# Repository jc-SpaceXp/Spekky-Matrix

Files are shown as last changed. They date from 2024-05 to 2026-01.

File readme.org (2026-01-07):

** Spekky Matrix
A FreeRTOS based project were a spectrum analyser is displayed on a LED matrix board run from a STM32 device
*** Detailed Description
A series of cascaded STP16CP05 LED IC drivers forms a 8x32 SMD (0603 Imperial)
LED matrix. This LED matrix then displays the fast fourier transform (FFT) of
an incoming audio signal picked up by a I2S digital microphone. The incoming
audio is a double buffered DMA signal. The LED matrix is driven via the
STM32's SPI interface. All while internal hardware timers and FreeRTOS are
responsible for accurate timing e.g. refresh rate of LED matrix and data
acquisition.

The Manhattan prototype uses a MAX7219 based 8x8 LED matrix breakout board
which was then cascaded to for a 8x32 LED matrix as well. In the PCB version
the STP16CP05 LED IC driver replaces the MAX7219 8x8 LED matrix.
*** Tools
The following tools are needed to build this project
- make
- [[https://developer.arm.com/downloads/-/gnu-rm][arm-none-eabi-gcc]]
- [[https://gcc.gnu.org/][gcc]] (for unit tests)
- [[https://github.com/stlink-org/stlink][st-flash]] in order to interact with the STM32
*** Progress / Milestones
- [X] Create LED matrix driver for MAX7219 devices
- [X] Drive LED matrix from STM32 using FreeRTOS
- [X] Run FFT off target
- [X] Verify FFT on target (using off target results as a guide)
- [X] Verify that LED matrix can be driven alongside FFT code (manually verified, no delays etc.)
- [X] Capture data from mic
- [X] Verify output of mic from raw logic analyser data (using SigPlotI2S)
- [X] Capture data from mic via DMA
- [X] Perform FFT on this raw logic analyser data with a sine wave test tone (off-target)
- [X] Animate FFT graphs to get a rough estimate of how the LED matrix will display it (off-target)
- [X] Perform FFT on mic data sampled by STM32 with a sine wave test tone (off-target)
- [X] Verify that LED matrix can be driven along with data capture and processing
- [X] Perform FFT on captured mic data to drive LED matrix
- [X] Adapt project to PCB
*** I2S Mic FFT Data Visualised
**** Logic Analyser Data (Sine 1kHz Test Tone)
FFT size = 64, start offset = 0, next offset = 32, FPS = 4

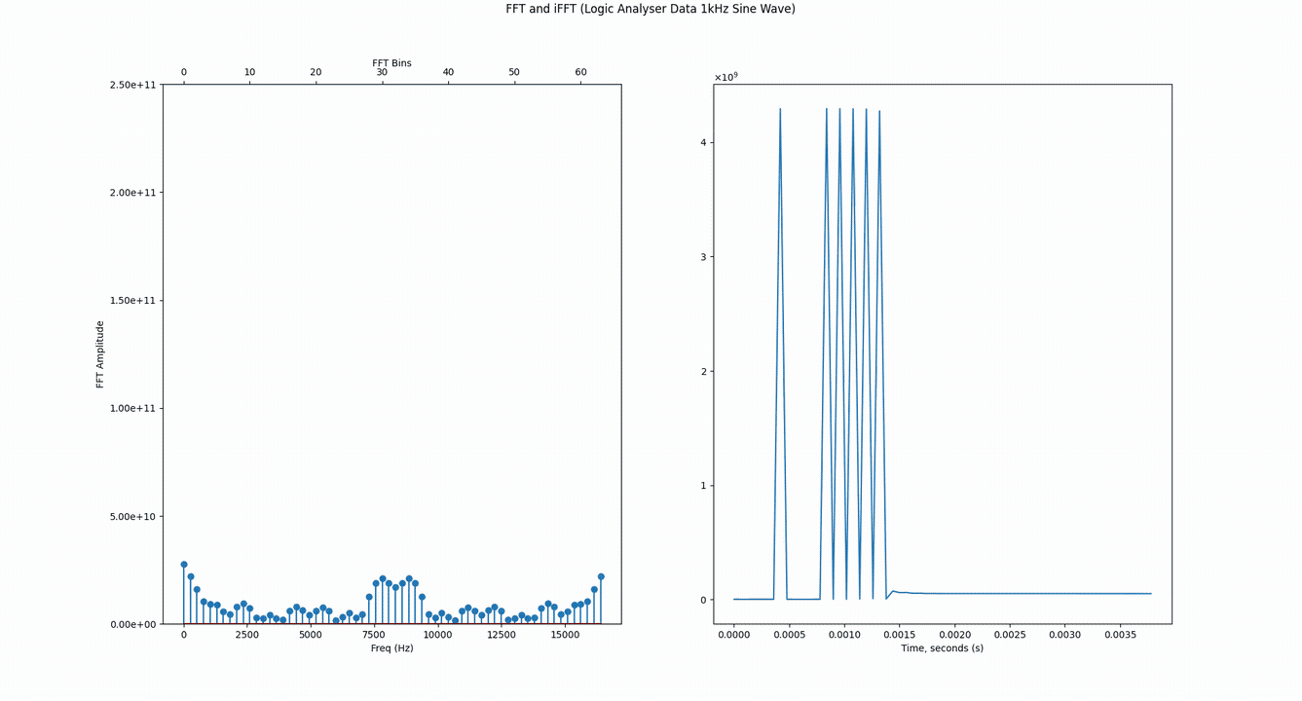
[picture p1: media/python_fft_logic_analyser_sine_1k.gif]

**** Spekky Matrix Calculations
FFT size = 64, bin resolution = (1/60E-6)/64 --> ~260Hz

Note: I measured one Ws period as 60us on PulseView hence the 1/60E-6 above
***** 8x32 LED Matrix (Sine 2kHz Test Tone)
Peak expected at the 7th/8th bin (2000 / 260 = ~7.69)

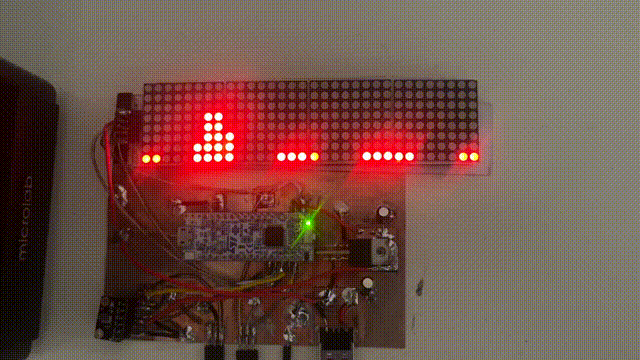
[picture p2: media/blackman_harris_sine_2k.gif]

***** 8x32 LED Matrix (Sine 4kHz Test Tone)
Peak expected at the 15th/16th bin (4000 / 260 = ~15.36)


***** 8x32 LED Matrix (Sine Sweep Test)
Since the I2S Ws period is 60us, this gives us a sampling frequency of 16.66 kHz.
 Giving us a visual representation of 0-8.88 kHz with Spekky Matrix

[[https://www.youtube.com/watch?v=dU80Fagdy28][Sine sweep source (youtube link)]]

Note: Gif is played at 2.5x speed, see mp4 for realtime playback and audio of sweep test

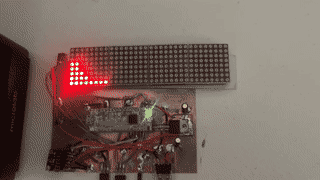
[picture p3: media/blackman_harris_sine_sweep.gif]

*** Schematic
[[file:schematic_v26.pdf]]
*** KiCad PCB
**** BOM
[[file:pcb/kicad/spekky_matrix_bom.csv]]
**** 3D Renders
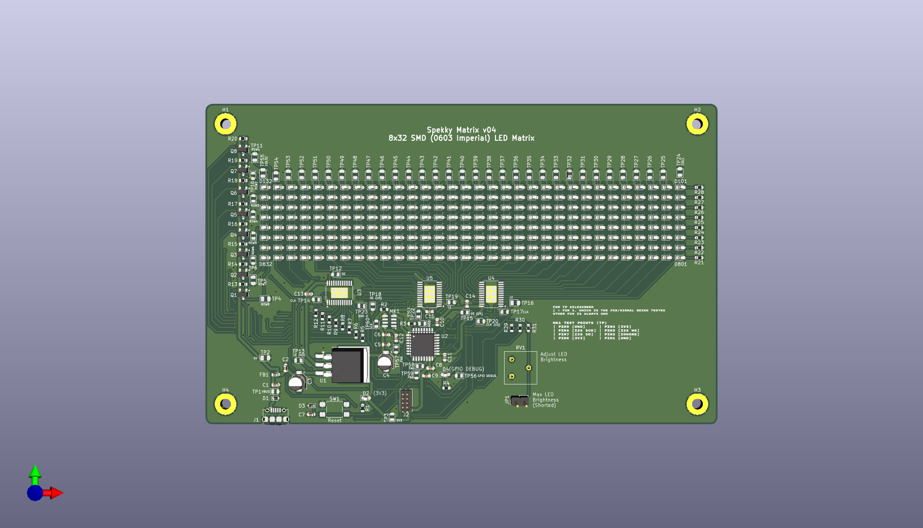
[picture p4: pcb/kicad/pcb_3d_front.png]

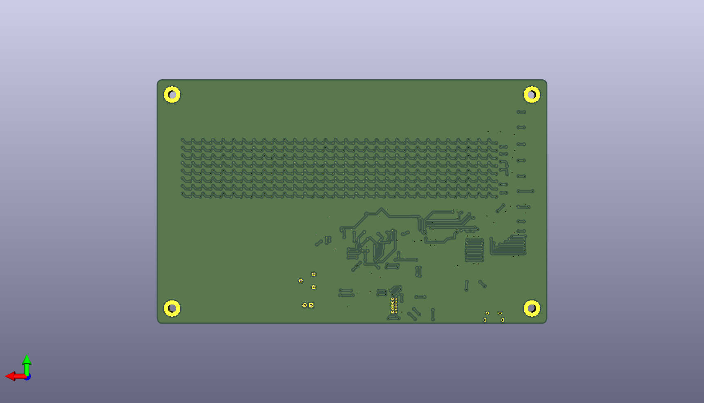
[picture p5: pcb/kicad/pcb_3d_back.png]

**** PCB v01 Test Patterns
Only displaying test patterns on PCB as v01 has the I2S footprint in the wrong orientation.

Attempted fix hasn't worked, PCB revision v04 contains fixed I2S footprint and test points.
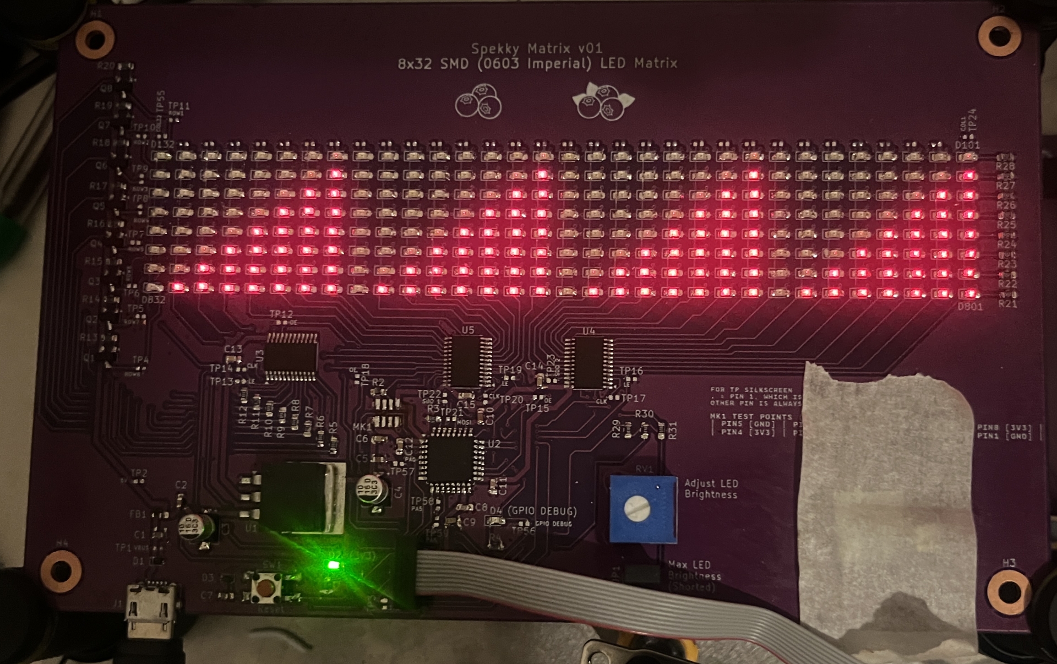
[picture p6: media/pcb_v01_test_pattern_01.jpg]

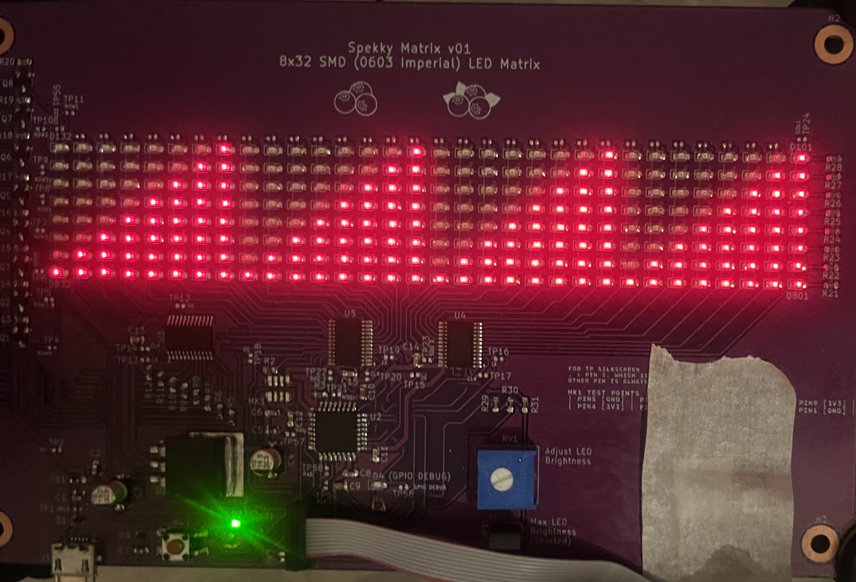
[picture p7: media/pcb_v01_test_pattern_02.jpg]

*** Execution Timeline
Rough timing of how long each task/sub-task takes to complete

Actual times are a mean of the traces from the timing branch
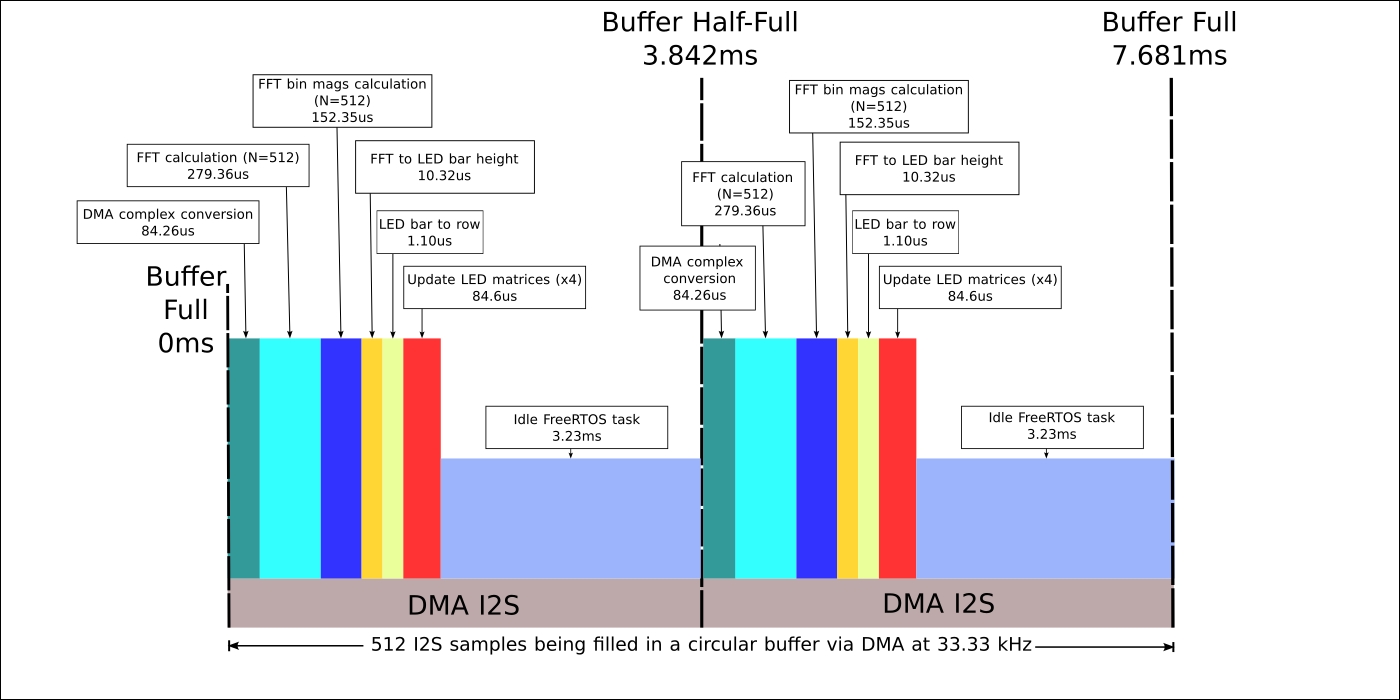
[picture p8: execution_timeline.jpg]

*** Submodules
- [[https://www.freertos.org/][FreeRTOS]]
- [[https://www.arm.com/technologies/cmsis][CMSIS V6]]
- [[https://github.com/ARM-software/CMSIS-DSP][ARM CMSIS DSP]]
- [[https://github.com/STMicroelectronics/stm32g4xx-nucleo-bsp][STM32G4xx Nucleo BSP]]
- [[https://github.com/STMicroelectronics/stm32g4xx_hal_driver][STM32G4 HAL]]
- [[https://github.com/STMicroelectronics/cmsis_device_g4][CMSIS G4]] CMSIS device library
- [[https://github.com/silentbicycle/greatest][Greatest]] C test framework
- [[https://github.com/meekrosoft/fff][fff]] C test doubles
- [[https://github.com/lucasssvaz/SigPlotI2S][SigPlotI2S]] Plot I2S PulseView/Sigrok output data

CMSIS will also produce linker warnings due to newlib e.g. "_write is not
implemented and will always fail". There is quite a bit of a size overhead
when pulling in all the CMSIS modules. An average project would be
around ~100Mb. This increases with FreeRTOS too.

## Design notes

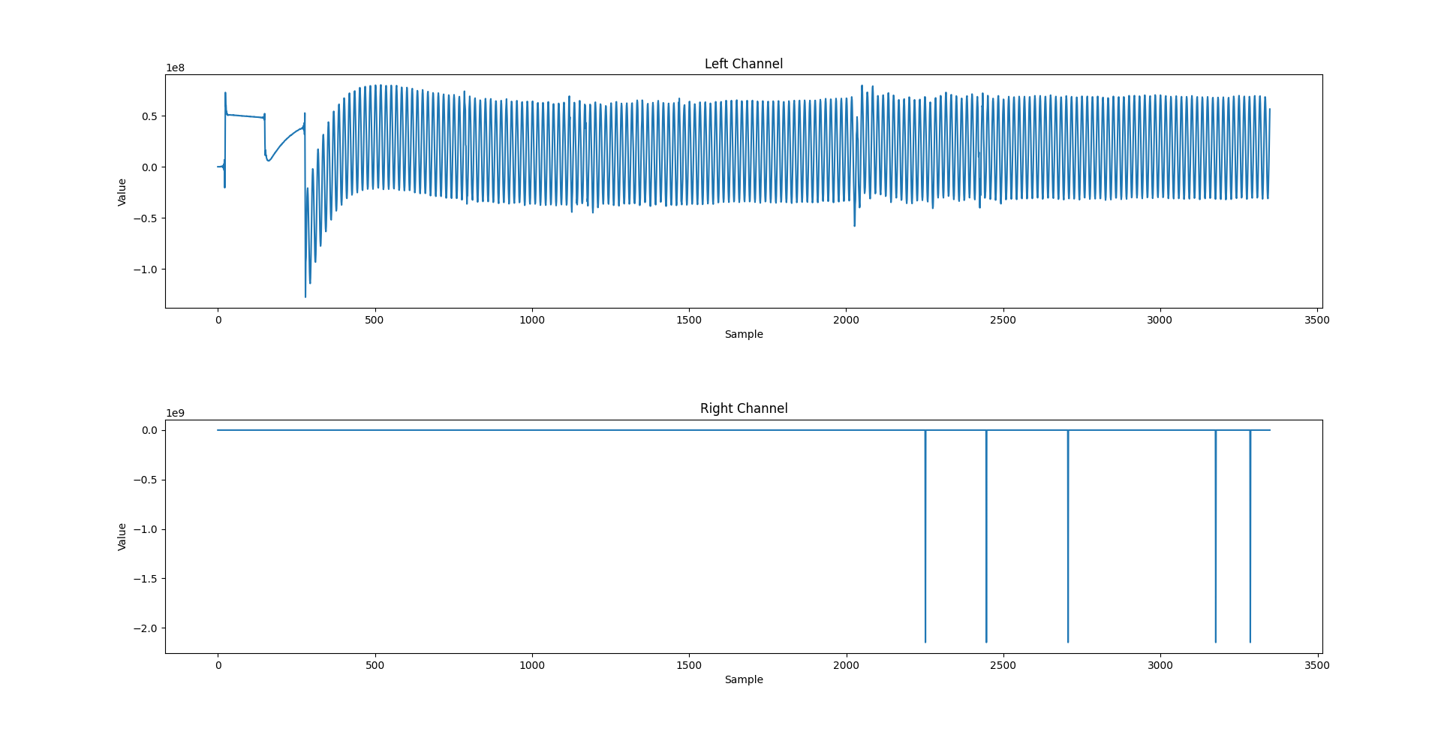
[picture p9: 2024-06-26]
traces/002_4d59f3e_fermion_mic_check_32_bit_frame_1kHz_sine_tone_on_phone_speakers_DATA_OUT.png

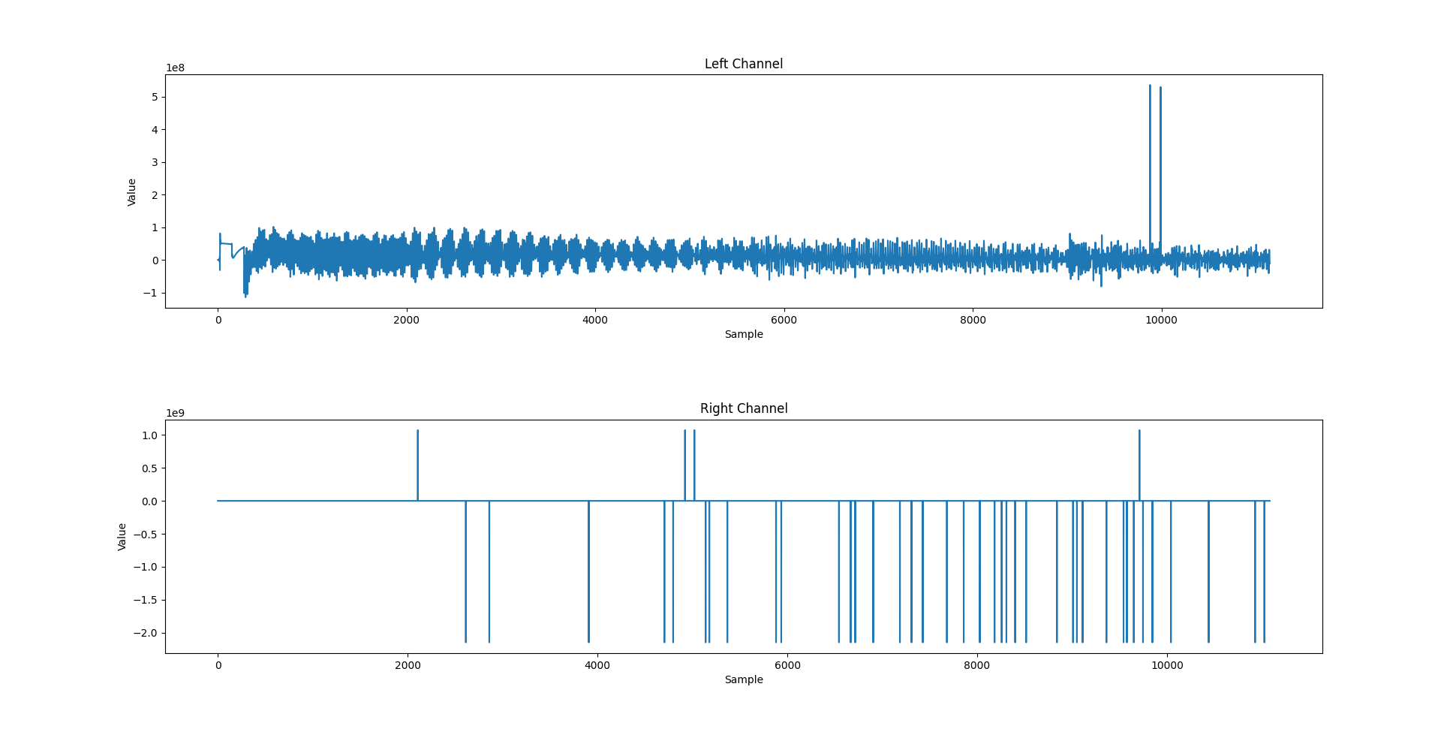
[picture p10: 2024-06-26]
traces/003_4d59f3e_fermion_mic_check_32_bit_frame_cimm_revival_on_phone_speakers_DATA_OUT.png

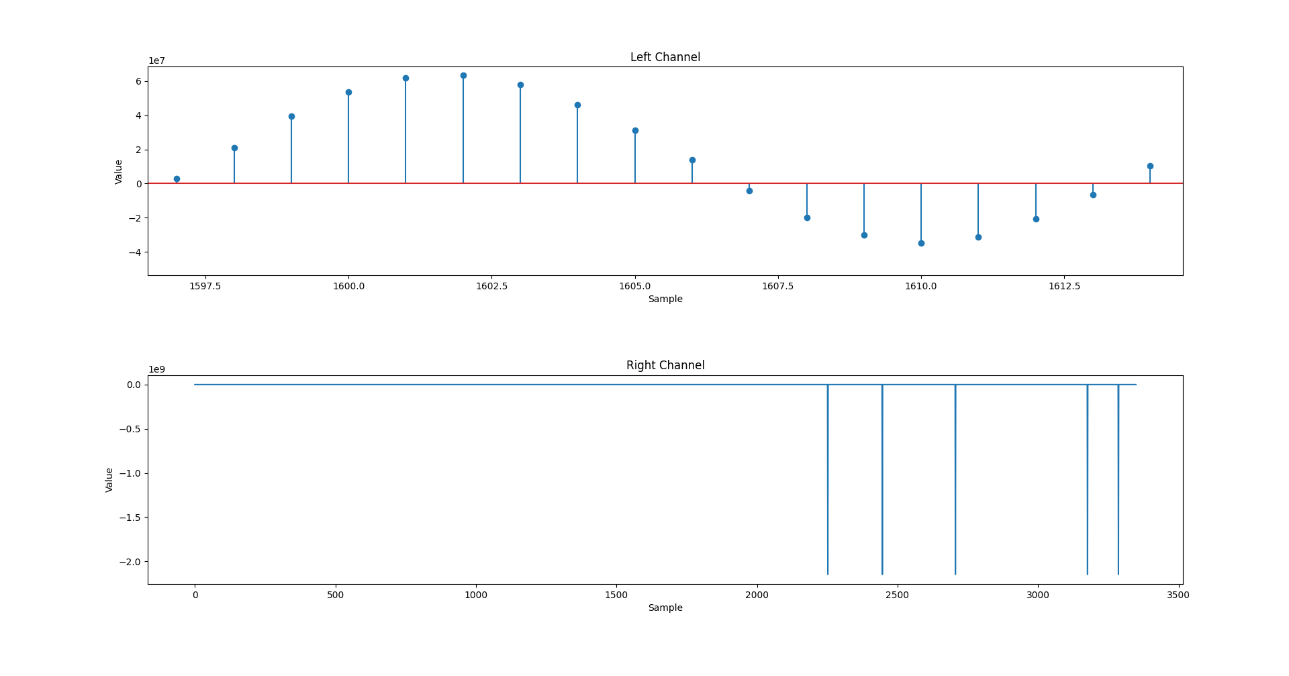
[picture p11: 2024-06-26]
traces/002_4d59f3e_fermion_mic_check_32_bit_frame_1kHz_sine_tone_on_phone_speakers_DATA_OUT_zoom_2_stem_one_period.png

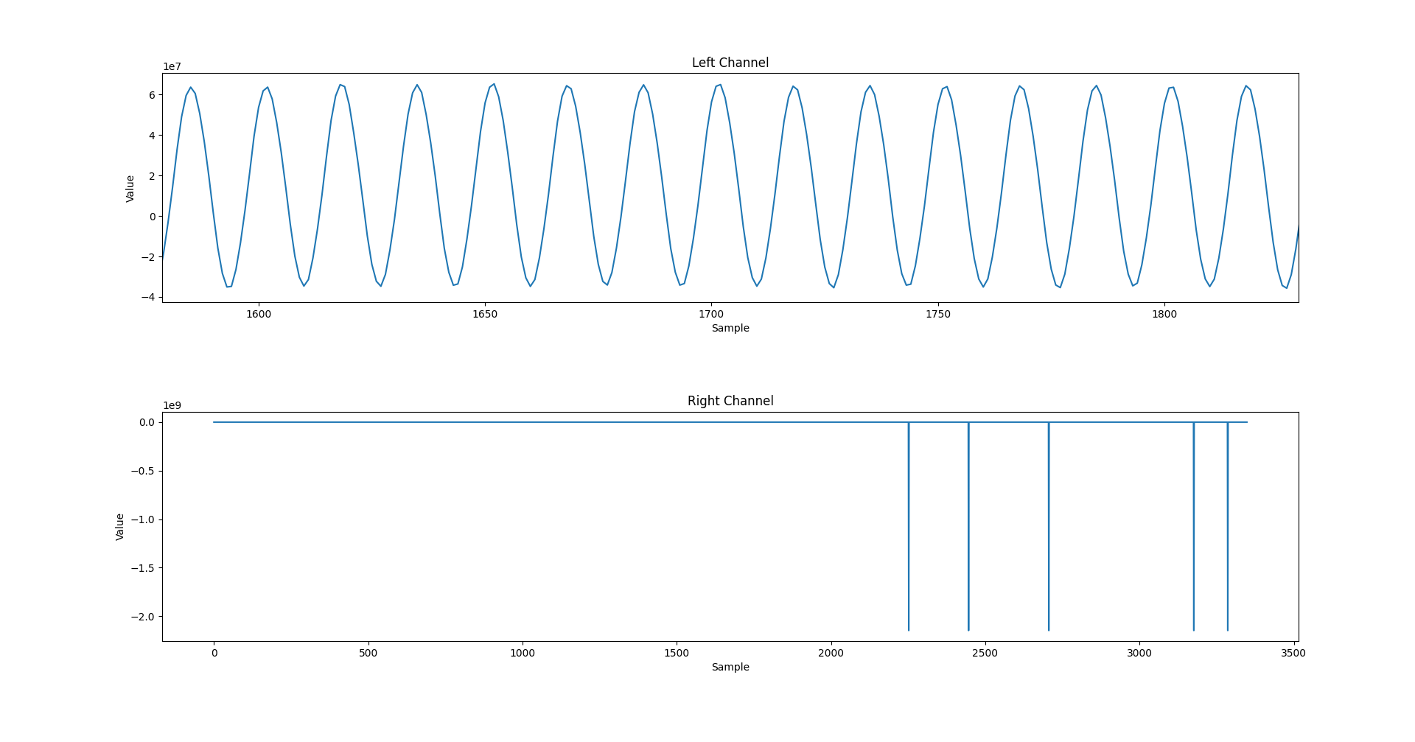
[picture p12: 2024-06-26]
traces/002_4d59f3e_fermion_mic_check_32_bit_frame_1kHz_sine_tone_on_phone_speakers_DATA_OUT_zoom_1.png

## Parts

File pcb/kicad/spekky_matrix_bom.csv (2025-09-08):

Reference | Qty | MPN | Value | Footprint | DNP
C1 | 1 | GCM188R71H103KA37J | 10n | Capacitor_SMD:C_0603_1608Metric
C2,C6-C8,C11-C15 | 9 | C0603C104J3RACTU | 100n | Capacitor_SMD:C_0603_1608Metric
C3,C4 | 2 | EDH106M016A9BAA | 10u | Capacitor_SMD:CP_Elec_4x4.5
C5 | 1 | C1608X5R1A106K080AC | 10u | Capacitor_SMD:C_0603_1608Metric
C9 | 1 | GCG188L8EE105KA07D | 1u | Capacitor_SMD:C_0603_1608Metric
C10 | 1 | GRM188Z71C475KE21D | 4u7 | Capacitor_SMD:C_0603_1608Metric
D1,D3 | 2 | PESD5V0X1UAB,115 | PESD5V0X1UAB | Diode_SMD:D_SOD-523
D2 | 1 | LTST-C190KRKT | 3V3 LED (RED) | LED_SMD:LED_0603_1608Metric_Pad1.05x0.95mm_HandSolder
D4 | 1 | LTST-C190KGKT | GPIO Debug LED (GREEN) | LED_SMD:LED_0603_1608Metric_Pad1.05x0.95mm_HandSolder
D101-D132,D201-D232,D301-D332,D401-D432,D501-D532,D601-D632,D701-D732,D801-D832 | 256 | LTST-C190KRKT | LED Matrix (RED) | LED_SMD:LED_0603_1608Metric_Pad1.05x0.95mm_HandSolder
FB1 | 1 | HI2220R301R-10 | 300R @ 100 MHz | Inductor_SMD:L_0603_1608Metric
J1 | 1 | 10118194-0001LF | USB_B_Micro | Connector_USB:USB_Micro-B_Amphenol_10118194-0001LF_Horizontal
J2 | 1 | FTSH-105-01-L-D-K | Conn_ARM_JTAG_SWD_10 | Connector_PinHeader_1.27mm:PinHeader_2x05_P1.27mm_Vertical
MK1 | 1 | MSM261S4030H0R | MSM261S4030H0R I2S Mic | spekky_matrix:LGA-8_2x4_3.0x4.0mm_P1.0mm_Hand_Solder
Q1-Q8 | 8 | DMP3125L-7 | DMP3125L-7 | Package_TO_SOT_SMD:SOT-23
R1,R4,R13-R20,R29-R31 | 13 | RT0603DRE071KL | 1K | Resistor_SMD:R_0603_1608Metric
R2 | 1 | RP73PF1J100KBTDF | 100K | Resistor_SMD:R_0603_1608Metric
R3 | 1 | RT0603FRE0710KL | 10K | Resistor_SMD:R_0603_1608Metric
R5-R12 | 8 | RT0603FRE0710RL | 10R | Resistor_SMD:R_0603_1608Metric
R21-R28 | 8 | RT0603FRE075K1L | 5K1 | Resistor_SMD:R_0603_1608Metric
RV1 | 1 | 3386F-1-222LF | 2K2 | Potentiometer_THT:Potentiometer_Bourns_3386F_Vertical
SW1 | 1 | TL3305AF260QG | SW_Push | Button_Switch_SMD:SW_SPST_TL3305A
U1 | 1 | LMS1585AIS-3.3/NOPB | LMS1585AIS-3.3 | Package_TO_SOT_SMD:TO-263-3_TabPin2
U2 | 1 | STM32G431K8T6 | STM32G431K8Tx | Package_QFP:LQFP-32_7x7mm_P0.8mm
U3-U5 | 3 | STP16CP05XTTR | STP16CP05XT | Package_SO:HTSSOP-24-1EP_4.4x7.8mm_P0.65mm_EP3.2x5mm

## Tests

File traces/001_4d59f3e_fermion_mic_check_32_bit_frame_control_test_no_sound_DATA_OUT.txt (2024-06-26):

11597-11777 I²S: : Left channel: 00000000
11777-11957 I²S: : Right channel: 00000000
11957-12137 I²S: : Left channel: 00000000
12137-12317 I²S: : Right channel: 00000000
12317-12497 I²S: : Left channel: 00000000
12497-12678 I²S: : Right channel: 00000000
12678-12858 I²S: : Left channel: 0006a300
12858-13038 I²S: : Right channel: 00000000
13038-13218 I²S: : Left channel: 00f1eb00
13218-13398 I²S: : Right channel: 00000000
13398-13578 I²S: : Left channel: 00609a00
13578-13758 I²S: : Right channel: 00000800
13758-13938 I²S: : Left channel: 005923c0
13938-14118 I²S: : Right channel: 00000000
14118-14298 I²S: : Left channel: 004cf7e0
14298-14478 I²S: : Right channel: 00000000
14478-14658 I²S: : Left channel: 0049be00
14658-14838 I²S: : Right channel: 00000000
14838-15018 I²S: : Left channel: 003e1c00
15018-15199 I²S: : Right channel: 00000000
15199-15379 I²S: : Left channel: 004659e0
15379-15559 I²S: : Right channel: 00000000
15559-15739 I²S: : Left channel: 00393de0
15739-15919 I²S: : Right channel: 00000000
15919-16099 I²S: : Left channel: 0040dfe0
16099-16279 I²S: : Right channel: 00000000
16279-16459 I²S: : Left channel: 00312a00
16459-16639 I²S: : Right channel: 00000000
16639-16819 I²S: : Left channel: 003d7a00
16819-16999 I²S: : Right channel: 00000000
16999-17179 I²S: : Left channel: 001e8400
17179-17359 I²S: : Right channel: 00000000
17359-17539 I²S: : Left channel: 006c35f0
17539-17720 I²S: : Right channel: 00000000
17720-17900 I²S: : Left channel: ff5615e0
17900-18080 I²S: : Right channel: 00000000
18080-18260 I²S: : Left channel: 051bcbe0
18260-18440 I²S: : Right channel: 00000000
18440-18620 I²S: : Left channel: 658b2bf0
18620-18800 I²S: : Right channel: 00000000
18800-18980 I²S: : Left channel: 575567f1
18980-19160 I²S: : Right channel: 00000000
19160-19340 I²S: : Left channel: 4be61800
19340-19520 I²S: : Right channel: 00000000
19520-19700 I²S: : Left channel: 533fc800
19700-19880 I²S: : Right channel: 00000000
19880-20060 I²S: : Left channel: 52f0cdf0
20060-20241 I²S: : Right channel: 00000000
20241-20421 I²S: : Left channel: 4cef8be0
20421-20601 I²S: : Right channel: 00000000
20601-20781 I²S: : Left channel: 49f40ff0
20781-20961 I²S: : Right channel: 00000000
20961-21141 I²S: : Left channel: 4266c3f0
21141-21321 I²S: : Right channel: 00000000
21321-21501 I²S: : Left channel: 40b93ff8
21501-21681 I²S: : Right channel: 00000000
21681-21861 I²S: : Left channel: 3dbad200
21861-22041 I²S: : Right channel: 00000000
22041-22221 I²S: : Left channel: 3bfc6400
22221-22401 I²S: : Right channel: 00000000
22401-22582 I²S: : Left channel: 39958400
22582-22762 I²S: : Right channel: 00000000
22762-22942 I²S: : Left channel: 38227600
22942-23122 I²S: : Right channel: 00000000
23122-23302 I²S: : Left channel: 35e7ce00
23302-23482 I²S: : Right channel: 00000000
23482-23662 I²S: : Left channel: 343d0c00
23662-23842 I²S: : Right channel: 00000000
23842-24022 I²S: : Left channel: 3250e9f0
24022-24202 I²S: : Right channel: 00000000
24202-24382 I²S: : Left channel: 30e83000
24382-24562 I²S: : Right channel: 00000000
24562-24742 I²S: : Left channel: 2fe65000
24742-24922 I²S: : Right channel: 00000000
24922-25103 I²S: : Left channel: 2e806600
25103-25283 I²S: : Right channel: 00000000
25283-25463 I²S: : Left channel: 2db89200
25463-25643 I²S: : Right channel: 00000000
25643-25823 I²S: : Left channel: 2cef0ff0
25823-26003 I²S: : Right channel: 00000000
26003-26183 I²S: : Left channel: 2c3c5600
26183-26363 I²S: : Right channel: 00000000
26363-26543 I²S: : Left channel: 2b73c1f0
26543-26723 I²S: : Right channel: 00000000
26723-26903 I²S: : Left channel: 2b0777f4
26903-27083 I²S: : Right channel: 00000000
27083-27264 I²S: : Left channel: 2ab9fdf0
27264-27444 I²S: : Right channel: 00000000
27444-27624 I²S: : Left channel: 2a5f9df0
27624-27804 I²S: : Right channel: 00000000
27804-27984 I²S: : Left channel: 298a4df8
27984-28164 I²S: : Right channel: 00000000
28164-28344 I²S: : Left channel: 2966cdf0
28344-28524 I²S: : Right channel: 00000000
28524-28704 I²S: : Left channel: 290115f4
28704-28884 I²S: : Right channel: 00000000
28884-29065 I²S: : Left channel: 286a49e0
29065-29245 I²S: : Right channel: 00000000
29245-29425 I²S: : Left channel: 289969f0
29425-29605 I²S: : Right channel: 00000000
29605-29785 I²S: : Left channel: 2814ca00
29785-29965 I²S: : Right channel: 00000000
29965-30145 I²S: : Left channel: 27d1c1f0
30145-30325 I²S: : Right channel: 00000000
30325-30505 I²S: : Left channel: 2782f400
30505-30685 I²S: : Right channel: 00000000
30685-30866 I²S: : Left channel: 27459200
30866-31046 I²S: : Right channel: 00000000
31046-31226 I²S: : Left channel: 2717abf0
31226-31406 I²S: : Right channel: 00000000
31406-31586 I²S: : Left channel: 273b6600
31586-31766 I²S: : Right channel: 00000000
31766-31946 I²S: : Left channel: 26c11ff0
31946-32126 I²S: : Right channel: 00000000
32126-32306 I²S: : Left channel: 267afff1
32306-32486 I²S: : Right channel: 00000000
32486-32666 I²S: : Left channel: 268cc600
32666-32846 I²S: : Right channel: 00000000
32846-33026 I²S: : Left channel: 25e33c00
33026-33206 I²S: : Right channel: 00000000
33206-33386 I²S: : Left channel: 26351800
33386-33567 I²S: : Right channel: 00000000
33567-33747 I²S: : Left channel: 25a55de0
33747-33927 I²S: : Right channel: 00000000
33927-34107 I²S: : Left channel: 26890600
34107-34287 I²S: : Right channel: 00000000
34287-34467 I²S: : Left channel: 25aba600
34467-34647 I²S: : Right channel: 00000000
34647-34827 I²S: : Left channel: 260ee000
34827-35007 I²S: : Right channel: 00000000
35007-35187 I²S: : Left channel: 24dea7f4
35187-35367 I²S: : Right channel: 00000000
35367-35547 I²S: : Left channel: 252b9bf0
35547-35728 I²S: : Right channel: 00000000
35728-35908 I²S: : Left channel: 253e1ff0
35908-36088 I²S: : Right channel: 00000000
36088-36268 I²S: : Left channel: 24f047f0
36268-36448 I²S: : Right channel: 00000000
36448-36628 I²S: : Left channel: 25274e00
36628-36808 I²S: : Right channel: 00000000
36808-36988 I²S: : Left channel: 2437b600
36988-37168 I²S: : Right channel: 00000000
37168-37349 I²S: : Left channel: 252b75f0
37349-37529 I²S: : Right channel: 00000000
37529-37709 I²S: : Left channel: 2490e5f2
37709-37889 I²S: : Right channel: 00000000
37889-38069 I²S: : Left channel: 2484f9f0
38069-38249 I²S: : Right channel: 00000000
38249-38429 I²S: : Left channel: 24a403f0
38429-38609 I²S: : Right channel: 00000000
38609-38790 I²S: : Left channel: 23c8f1e0
38790-38970 I²S: : Right channel: 00000000
38970-39150 I²S: : Left channel: 248a8800
39150-39330 I²S: : Right channel: 00000000
39330-39510 I²S: : Left channel: 24653ff8
39510-39690 I²S: : Right channel: 00000000
39690-39870 I²S: : Left channel: 243a7ff0
39870-40050 I²S: : Right channel: 00000000
40050-40230 I²S: : Left channel: 2407dc00
40230-40410 I²S: : Right channel: 00000000
40410-40590 I²S: : Left channel: 23da9a00
40590-40771 I²S: : Right channel: 00000000
40771-40951 I²S: : Left channel: 24993c00
40951-41131 I²S: : Right channel: 00000000
41131-41311 I²S: : Left channel: 2379bc00
41311-41491 I²S: : Right channel: 00000000
41491-41671 I²S: : Left channel: 23e52600
41671-41851 I²S: : Right channel: 00000000
41851-42031 I²S: : Left channel: 23a07e00
42031-42211 I²S: : Right channel: 00000000
42211-42391 I²S: : Left channel: 231f2400
42391-42571 I²S: : Right channel: 00000000
42571-42751 I²S: : Left channel: 23a36800
42751-42931 I²S: : Right channel: 00000000
42931-43111 I²S: : Left channel: 231a0600
43111-43292 I²S: : Right channel: 00000000
43292-43472 I²S: : Left channel: 2355b600
43472-43652 I²S: : Right channel: 00000000
43652-43832 I²S: : Left channel: 23108400
43832-44012 I²S: : Right channel: 00000000
44012-44192 I²S: : Left channel: 2260eff8
44192-44372 I²S: : Right channel: 00000000
44372-44552 I²S: : Left channel: 2318a800
44552-44732 I²S: : Right channel: 00000000
44732-44912 I²S: : Left channel: 22d41600
44912-45092 I²S: : Right channel: 00000000
45092-45272 I²S: : Left channel: 22200600
45272-45452 I²S: : Right channel: 00000000
45452-45633 I²S: : Left channel: 22c137e0
45633-45813 I²S: : Right channel: 00000000
45813-45993 I²S: : Left channel: 228fc200
45993-46173 I²S: : Right channel: 00000000
46173-46353 I²S: : Left channel: 2227a5f0
46353-46533 I²S: : Right channel: 00000000
46533-46713 I²S: : Left channel: 22a72200
46713-46893 I²S: : Right channel: 00000000
46893-47073 I²S: : Left channel: 220f4400
47073-47253 I²S: : Right channel: 00000000
47253-47433 I²S: : Left channel: 2252fff0
47433-47613 I²S: : Right channel: 00000000
47613-47793 I²S: : Left channel: 22ac8800
47793-47973 I²S: : Right channel: 00000000
47973-48153 I²S: : Left channel: 21f74000
48153-48333 I²S: : Right channel: 00000000
48333-48513 I²S: : Left channel: 22304000
48513-48693 I²S: : Right channel: 00000000
48693-48874 I²S: : Left channel: 22a8bfe0
48874-49054 I²S: : Right channel: 00000000
49054-49234 I²S: : Left channel: 21f61200
49234-49414 I²S: : Right channel: 00000000
49414-49594 I²S: : Left channel: 2227c000
49594-49774 I²S: : Right channel: 00000000
49774-49954 I²S: : Left channel: 21dd8df0
49954-50134 I²S: : Right channel: 00000000
50134-50314 I²S: : Left channel: 212ad9f0
50314-50494 I²S: : Right channel: 00000000
50494-50674 I²S: : Left channel: 21ef0800
50674-50854 I²S: : Right channel: 00000000
50854-51034 I²S: : Left channel: 21d6cbf0
51034-51214 I²S: : Right channel: 00000000
51214-51394 I²S: : Left channel: 213c99f0
51394-51575 I²S: : Right channel: 00000000
51575-51755 I²S: : Left channel: 21c4f7e0
51755-51935 I²S: : Right channel: 00000000
51935-52115 I²S: : Left channel: 216b53f0
52115-52295 I²S: : Right channel: 00000000
52295-52475 I²S: : Left channel: 2176c200
52475-52655 I²S: : Right channel: 00000000
52655-52835 I²S: : Left channel: 218e13f0
52835-53015 I²S: : Right channel: 00000000
53015-53195 I²S: : Left channel: 215ff5f0
53195-53375 I²S: : Right channel: 00000000
53375-53555 I²S: : Left channel: 2179b3f0
53555-53735 I²S: : Right channel: 00000000
53735-53915 I²S: : Left channel: 210713f0
53915-54095 I²S: : Right channel: 00000000
54095-54275 I²S: : Left channel: 20ac9bf0
54275-54455 I²S: : Right channel: 00000000
54455-54635 I²S: : Left channel: 215cb5f0
54635-54815 I²S: : Right channel: 00000000
54815-54996 I²S: : Left channel: 20f605f0
54996-55176 I²S: : Right channel: 00000000
55176-55356 I²S: : Left channel: 20b47c00
55356-55536 I²S: : Right channel: 00000000
55536-55716 I²S: : Left channel: 21225800
55716-55896 I²S: : Right channel: 00000000
55896-56076 I²S: : Left channel: 2093ac00
56076-56256 I²S: : Right channel: 00000000
56256-56436 I²S: : Left channel: 20e39000
56436-56616 I²S: : Right channel: 00000000
56616-56796 I²S: : Left channel: 20f6cff0
56796-56976 I²S: : Right channel: 00000000
56976-57156 I²S: : Left channel: 204645f0
57156-57336 I²S: : Right channel: 00000000
57336-57516 I²S: : Left channel: 20f3c5e0
57516-57696 I²S: : Right channel: 00000000
57696-57877 I²S: : Left channel: 2104e5e0
57877-58057 I²S: : Right channel: 00000000
58057-58237 I²S: : Left channel: 206fa7f2
58237-58417 I²S: : Right channel: 00000000
58417-58597 I²S: : Left channel: 20d0d5f0
58597-58777 I²S: : Right channel: 00000000
58777-58957 I²S: : Left channel: 209257f0
58957-59137 I²S: : Right channel: 00000000
59137-59317 I²S: : Left channel: 204337f8
59317-59497 I²S: : Right channel: 00000000
59497-59677 I²S: : Left channel: 20888400
59677-59857 I²S: : Right channel: 00000000
59857-60037 I²S: : Left channel: 20727a00
60037-60217 I²S: : Right channel: 00000000
60217-60397 I²S: : Left channel: 200187f0
60397-60577 I²S: : Right channel: 00000000
60577-60758 I²S: : Left channel: 20673ff0
60758-60938 I²S: : Right channel: 00000000
60938-61118 I²S: : Left channel: 206aca00
61118-61298 I²S: : Right channel: 00000000
61298-61478 I²S: : Left channel: 1fc1f7f0
61478-61658 I²S: : Right channel: 00000000
61658-61838 I²S: : Left channel: 2050bdf1
61838-62018 I²S: : Right channel: 00000000
62018-62198 I²S: : Left channel: 2041a000
62198-62378 I²S: : Right channel: 00000000
62378-62558 I²S: : Left channel: 1fab9fe0
62558-62738 I²S: : Right channel: 00000000
62738-62919 I²S: : Left channel: 1fffadf0
62919-63099 I²S: : Right channel: 00000000
63099-63279 I²S: : Left channel: 1ff23800
63279-63459 I²S: : Right channel: 00000000
63459-63639 I²S: : Left channel: 1f713df0
63639-63819 I²S: : Right channel: 00000000
63819-63999 I²S: : Left channel: 201225f0
63999-64179 I²S: : Right channel: 00000000
64179-64359 I²S: : Left channel: 1ff0d800
64359-64539 I²S: : Right channel: 00000000
64539-64719 I²S: : Left channel: 1fbdcdf0
64719-64899 I²S: : Right channel: 00000000
64899-65080 I²S: : Left channel: 200527e0
65080-65260 I²S: : Right channel: 00000000
65260-65440 I²S: : Left channel: 1ff08800
65440-65620 I²S: : Right channel: 00000000
65620-65800 I²S: : Left channel: 20007800
65800-65980 I²S: : Right channel: 00000000
65980-66160 I²S: : Left channel: 1fd50bf0
66160-66340 I²S: : Right channel: 00000000
66340-66520 I²S: : Left channel: 1f7b5ff8
66520-66700 I²S: : Right channel: 00000000
66700-66880 I²S: : Left channel: 1ff3fa00
66880-67060 I²S: : Right channel: 00000000
67060-67240 I²S: : Left channel: 1fb6ac00
67240-67420 I²S: : Right channel: 00000000
67420-67600 I²S: : Left channel: 1f889c00
67600-67780 I²S: : Right channel: 00000000
67780-67960 I²S: : Left channel: 1fd255f0
67960-68140 I²S: : Right channel: 00000000
68140-68320 I²S: : Left channel: 1f733bf0
68320-68500 I²S: : Right channel: 00000000
68500-68680 I²S: : Left channel: 1f792800
68680-68861 I²S: : Right channel: 00000000
68861-69041 I²S: : Left channel: 1fe78a00
69041-69221 I²S: : Right channel: 00000000
69221-69401 I²S: : Left channel: 1f8e1000
69401-69581 I²S: : Right channel: 00000000
69581-69761 I²S: : Left channel: 1f6c09f8
69761-69941 I²S: : Right channel: 00000000
69941-70121 I²S: : Left channel: 1fa7dc00
70121-70301 I²S: : Right channel: 00000000
70301-70481 I²S: : Left channel: 1ef283f0
70481-70661 I²S: : Right channel: 00000000
70661-70841 I²S: : Left channel: 1f8555f0
70841-71021 I²S: : Right channel: 00000000
71021-71201 I²S: : Left channel: 1fa01c00
71201-71381 I²S: : Right channel: 00000000
71381-71561 I²S: : Left channel: 1f105a00
71561-71742 I²S: : Right channel: 00000000
71742-71922 I²S: : Left channel: 1f2b1c00
71922-72102 I²S: : Right channel: 00000000
72102-72282 I²S: : Left channel: 1f1f39f0
72282-72462 I²S: : Right channel: 00000000
72462-72642 I²S: : Left channel: 1e94ec00
72642-72822 I²S: : Right channel: 00000000
72822-73002 I²S: : Left channel: 1ef0e800
73002-73182 I²S: : Right channel: 00000000
73182-73362 I²S: : Left channel: 1ef651d0
73362-73542 I²S: : Right channel: 00000000
73542-73722 I²S: : Left channel: 1ebf3a00
73722-73902 I²S: : Right channel: 00000000
73902-74083 I²S: : Left channel: 1f08ddf0
74083-74263 I²S: : Right channel: 00000000
74263-74443 I²S: : Left channel: 1ea53e00
74443-74623 I²S: : Right channel: 00000000
74623-74803 I²S: : Left channel: 1e83f9f0
74803-74983 I²S: : Right channel: 00000000
74983-75163 I²S: : Left channel: 1f666400
75163-75343 I²S: : Right channel: 00000000
75343-75523 I²S: : Left channel: 1ef651f0
75523-75703 I²S: : Right channel: 00000000
75703-75883 I²S: : Left channel: 1eafd000
75883-76063 I²S: : Right channel: 00000000
76063-76243 I²S: : Left channel: 1ecfc000
76243-76423 I²S: : Right channel: 00000000
76423-76603 I²S: : Left channel: 1f118200
76603-76783 I²S: : Right channel: 00000000
76783-76963 I²S: : Left channel: 1e588800
76963-77143 I²S: : Right channel: 00000000
77143-77324 I²S: : Left channel: 1ecdabe0
77324-77504 I²S: : Right channel: 00000000
77504-77684 I²S: : Left channel: 1efc8be0
77684-77864 I²S: : Right channel: 00000000
77864-78044 I²S: : Left channel: 1e937200
78044-78224 I²S: : Right channel: 00000000
78224-78404 I²S: : Left channel: 1e431200
78404-78584 I²S: : Right channel: 00000000
78584-78764 I²S: : Left channel: 1e57f9f8
78764-78944 I²S: : Right channel: 00000000
78944-79124 I²S: : Left channel: 1ea55a00
79124-79304 I²S: : Right channel: 00000000
79304-79484 I²S: : Left channel: 1e5955f1
79484-79664 I²S: : Right channel: 00000000
79664-79844 I²S: : Left channel: 1df237f0
79844-80024 I²S: : Right channel: 00000000
80024-80204 I²S: : Left channel: 1e51f7f0
80204-80384 I²S: : Right channel: 00000000
80384-80564 I²S: : Left channel: 1dd01a00
80564-80744 I²S: : Right channel: 00000000
80744-80924 I²S: : Left channel: 1df805f0
80924-81105 I²S: : Right channel: 00000000
81105-81285 I²S: : Left channel: 1e3b1de0
81285-81465 I²S: : Right channel: 00000000
81465-81645 I²S: : Left channel: 1dad3000
81645-81825 I²S: : Right channel: 00000000
81825-82005 I²S: : Left channel: 1df18a00
82005-82185 I²S: : Right channel: 00000000
82185-82365 I²S: : Left channel: 1e177000
82365-82545 I²S: : Right channel: 00000000
82545-82725 I²S: : Left channel: 1d9511f0
82725-82905 I²S: : Right channel: 00000000
82905-83085 I²S: : Left channel: 1e1b53f0
83085-83265 I²S: : Right channel: 00000000
83265-83446 I²S: : Left channel: 1dfc5e00
83446-83626 I²S: : Right channel: 00000000
83626-83806 I²S: : Left channel: 1df7fbf0
83806-83986 I²S: : Right channel: 00000000
83986-84166 I²S: : Left channel: 1e0f9800
84166-84346 I²S: : Right channel: 00000000
84346-84526 I²S: : Left channel: 1e6211f0
84526-84706 I²S: : Right channel: 00000000
84706-84886 I²S: : Left channel: 1e022600
84886-85067 I²S: : Right channel: 00000000
85067-85247 I²S: : Left channel: 1e4cc800
85247-85427 I²S: : Right channel: 00000000
85427-85607 I²S: : Left channel: 1df86600
85607-85787 I²S: : Right channel: 00000000
85787-85967 I²S: : Left channel: 1d83c5f0
85967-86147 I²S: : Right channel: 00000000
86147-86327 I²S: : Left channel: 1e213e00
86327-86507 I²S: : Right channel: 00000000
86507-86687 I²S: : Left channel: 1ddeddf0
86687-86868 I²S: : Right channel: 00000000
86868-87048 I²S: : Left channel: 1d210800
87048-87228 I²S: : Right channel: 00000000
87228-87408 I²S: : Left channel: 1d710e00
87408-87588 I²S: : Right channel: 00000000
87588-87768 I²S: : Left channel: 1d9fb9f0
87768-87948 I²S: : Right channel: 00000000
87948-88128 I²S: : Left channel: 1d014c00
88128-88309 I²S: : Right channel: 00000000
88309-88489 I²S: : Left channel: 1d77cbe0
88489-88669 I²S: : Right channel: 00000000
88669-88849 I²S: : Left channel: 1d525000
88849-89029 I²S: : Right channel: 00000000
89029-89209 I²S: : Left channel: 1d1aae00
89209-89389 I²S: : Right channel: 00000000
89389-89569 I²S: : Left channel: 1d384e00
89569-89750 I²S: : Right channel: 00000000
89750-89930 I²S: : Left channel: 1d301de0
89930-90110 I²S: : Right channel: 00000000
90110-90290 I²S: : Left channel: 1d480e00
90290-90470 I²S: : Right channel: 00000000
90470-90650 I²S: : Left channel: 1d4b49f0
90650-90830 I²S: : Right channel: 00000000
90830-91010 I²S: : Left channel: 1cdace00
91010-91190 I²S: : Right channel: 00000000
91190-91371 I²S: : Left channel: 1cea2df0
91371-91551 I²S: : Right channel: 00000000
91551-91731 I²S: : Left channel: 1cd80df0
91731-91911 I²S: : Right channel: 00000000
91911-92091 I²S: : Left channel: 1d40d000
92091-92271 I²S: : Right channel: 00000000
92271-92451 I²S: : Left channel: 1d4fe000
92451-92631 I²S: : Right channel: 00000000
92631-92812 I²S: : Left channel: 1cd85fe0
92812-92992 I²S: : Right channel: 00000000
92992-93172 I²S: : Left channel: 1cf09ff0
93172-93352 I²S: : Right channel: 00000000
93352-93532 I²S: : Left channel: 1d37b3f0
93532-93712 I²S: : Right channel: 00000000
93712-93892 I²S: : Left channel: 1ce579d0
93892-94072 I²S: : Right channel: 00000000
94072-94252 I²S: : Left channel: 1d220a00
94252-94433 I²S: : Right channel: 00000000
94433-94613 I²S: : Left channel: 1d180400
94613-94793 I²S: : Right channel: 00000000
94793-94973 I²S: : Left channel: 1cd991f0
94973-95153 I²S: : Right channel: 00000000
95153-95333 I²S: : Left channel: 1ced15f0
95333-95513 I²S: : Right channel: 00000000
95513-95694 I²S: : Left channel: 1d099e00
95694-95874 I²S: : Right channel: 00000000
95874-96054 I²S: : Left channel: 1cc8dff0
96054-96234 I²S: : Right channel: 00000000
96234-96414 I²S: : Left channel: 1cb7f5f1
96414-96594 I²S: : Right channel: 00000000
96594-96774 I²S: : Left channel: 1cd89ff0
96774-96954 I²S: : Right channel: 00000000
96954-97135 I²S: : Left channel: 1c46bdf0
97135-97315 I²S: : Right channel: 00000000
97315-97495 I²S: : Left channel: 1c9a9200
97495-97675 I²S: : Right channel: 00000000
97675-97855 I²S: : Left channel: 1c39d3f0
97855-98035 I²S: : Right channel: 00000000
98035-98215 I²S: : Left channel: 1c557e00
98215-98396 I²S: : Right channel: 00000000
98396-98576 I²S: : Left channel: 1c2767f0
98576-98756 I²S: : Right channel: 00000000
98756-98936 I²S: : Left channel: 1bf541f1
98936-99116 I²S: : Right channel: 00000000
99116-99296 I²S: : Left channel: 1bf885f0
99296-99477 I²S: : Right channel: 00000000
99477-99657 I²S: : Left channel: 1c75c200
99657-99837 I²S: : Right channel: 00000000
99837-100017 I²S: : Left channel: 1c1f19f1
100017-100197 I²S: : Right channel: 00000000
100197-100377 I²S: : Left channel: 1c60abf0
100377-100558 I²S: : Right channel: 00000000
100558-100738 I²S: : Left channel: 1c2491f0
100738-100918 I²S: : Right channel: 00000000
100918-101098 I²S: : Left channel: 1c4491f0
101098-101278 I²S: : Right channel: 00000000
101278-101458 I²S: : Left channel: 1c669600
101458-101639 I²S: : Right channel: 00000000
101639-101819 I²S: : Left channel: 1c20c400
101819-101999 I²S: : Right channel: 00000000
101999-102179 I²S: : Left channel: 1c87e200
102179-102359 I²S: : Right channel: 00000000
102359-102539 I²S: : Left channel: 1c611df0
102539-102719 I²S: : Right channel: 00000000
102719-102900 I²S: : Left channel: 1bcaf5f0
102900-103080 I²S: : Right channel: 00000000
103080-103260 I²S: : Left channel: 1c4d2e00
103260-103440 I²S: : Right channel: 00000000
103440-103620 I²S: : Left channel: 1c26be00
103620-103800 I²S: : Right channel: 00000000
103800-103980 I²S: : Left channel: 1bd2b1f0
103980-104160 I²S: : Right channel: 00000000
104160-104340 I²S: : Left channel: 1c3a3bf0
104340-104520 I²S: : Right channel: 00000000
104520-104701 I²S: : Left channel: 1c458000
104701-104881 I²S: : Right channel: 00000000
104881-105061 I²S: : Left channel: 1befcdf0
105061-105241 I²S: : Right channel: 00000000
105241-105421 I²S: : Left channel: 1bdeddf0
105421-105601 I²S: : Right channel: 00000000
105601-105781 I²S: : Left channel: 1beecbf0
105781-105961 I²S: : Right channel: 00000000
105961-106141 I²S: : Left channel: 1bea79e0
106141-106321 I²S: : Right channel: 00000000
106321-106501 I²S: : Left channel: 1bd87e00
106501-106681 I²S: : Right channel: 00000000
106681-106862 I²S: : Left channel: 1bb3a5f0
106862-107042 I²S: : Right channel: 00000000
107042-107222 I²S: : Left channel: 1bd9be00
107222-107402 I²S: : Right channel: 00000000
107402-107582 I²S: : Left channel: 1bca4400
107582-107762 I²S: : Right channel: 00000000
107762-107942 I²S: : Left channel: 1b759000
107942-108122 I²S: : Right channel: 00000000
108122-108302 I²S: : Left channel: 1bc1b3f0
108302-108482 I²S: : Right channel: 00000000
108482-108663 I²S: : Left channel: 1b5c0000
108663-108843 I²S: : Right channel: 00000000
108843-109023 I²S: : Left channel: 1b562bf0
109023-109203 I²S: : Right channel: 00000000
109203-109383 I²S: : Left channel: 1b943a00
109383-109563 I²S: : Right channel: 00000000
109563-109743 I²S: : Left channel: 1b492200
109743-109923 I²S: : Right channel: 00000000
109923-110103 I²S: : Left channel: 1b8a6600
110103-110283 I²S: : Right channel: 00000000
110283-110463 I²S: : Left channel: 1b8267f0
110463-110643 I²S: : Right channel: 00000000
110643-110823 I²S: : Left channel: 1b934df0
110823-111003 I²S: : Right channel: 00000000
111003-111184 I²S: : Left channel: 1ba54400
111184-111364 I²S: : Right channel: 00000000
111364-111544 I²S: : Left channel: 1b794e00
111544-111724 I²S: : Right channel: 00000000
111724-111904 I²S: : Left channel: 1b27de00
111904-112084 I²S: : Right channel: 00000000
112084-112264 I²S: : Left channel: 1ba75200
112264-112444 I²S: : Right channel: 00000000
112444-112624 I²S: : Left channel: 1b8049f0
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

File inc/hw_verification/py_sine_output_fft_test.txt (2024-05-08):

(8.284213399999999+0j)
(8.62636695114758-4.424957927965547j)
(9.837655582397456-10.04498064851128j)
(12.794667938009676-19.44358075520538j)
(21.79799241098727-43.69024457265637j)
(185.8862500637988-459.33900737222393j)
(-23.454165006306724+68.40280056615032j)
(-10.268408946519799+34.27125015501009j)
(-6.328246943716139+23.617591005544597j)
(-4.47101654120538+18.3241927030198j)
(-3.4080363581534416+15.116500123472981j)
(-2.72896578329462+12.943286370280983j)
(-2.263054899871338+11.361925306020034j)
(-1.9268740575397167+10.152844572073938j)
(-1.6749973412965635+9.194310393498727j)
(-1.480675546412971+8.413152678134779j)
(-1.3271911984704772+7.762601957291322j)
(-1.203596782292827+7.2112821205525774j)
(-1.102445324614854+6.737304691649097j)
(-1.0185108096820814+6.324900803844347j)
(-0.9480277848889226+5.962399745092216j)
(-0.8882215032173445+5.640963865662353j)
(-0.8370071447925542+5.353767901379721j)
(-0.792791445801196+5.095449964509767j)
(-0.7543384331549321+4.861734326033611j)
(-0.7206764899426952+4.649166080864622j)
(-0.6910321576714782+4.454920791830286j)
(-0.6647845770218662+4.276664588194248j)
(-0.6414284226252369+4.11245136637583j)
(-0.6205502248551666+3.9606439572103445j)
(-0.6018084180172082+3.819854534934694j)
(-0.5849187785819921+3.6888982725001123j)
(-0.5696431718500778+3.5667570721919253j)
(-0.5557808071161664+3.4525508763208888j)
(-0.5431613800246243+3.345514759331028j)
(-0.531639646845725+3.2449804798143167j)
(-0.5210911685190256+3.150361374577602j)
(-0.5114085507699468+3.0611406243841364j)
(-0.5024991425033886+2.9768602353079214j)
(-0.4942822907519545+2.897113502264887j)
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

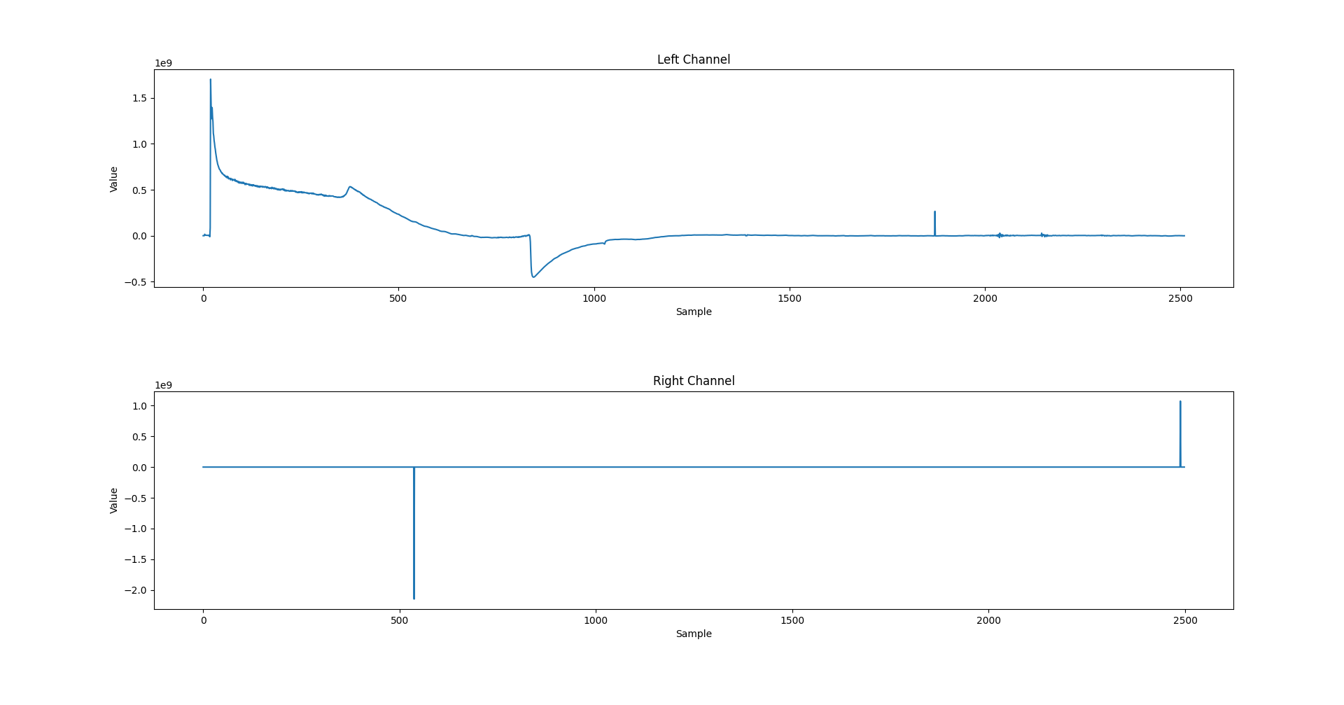
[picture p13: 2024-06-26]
traces/001_4d59f3e_fermion_mic_check_32_bit_frame_control_test_no_sound_DATA_OUT.png

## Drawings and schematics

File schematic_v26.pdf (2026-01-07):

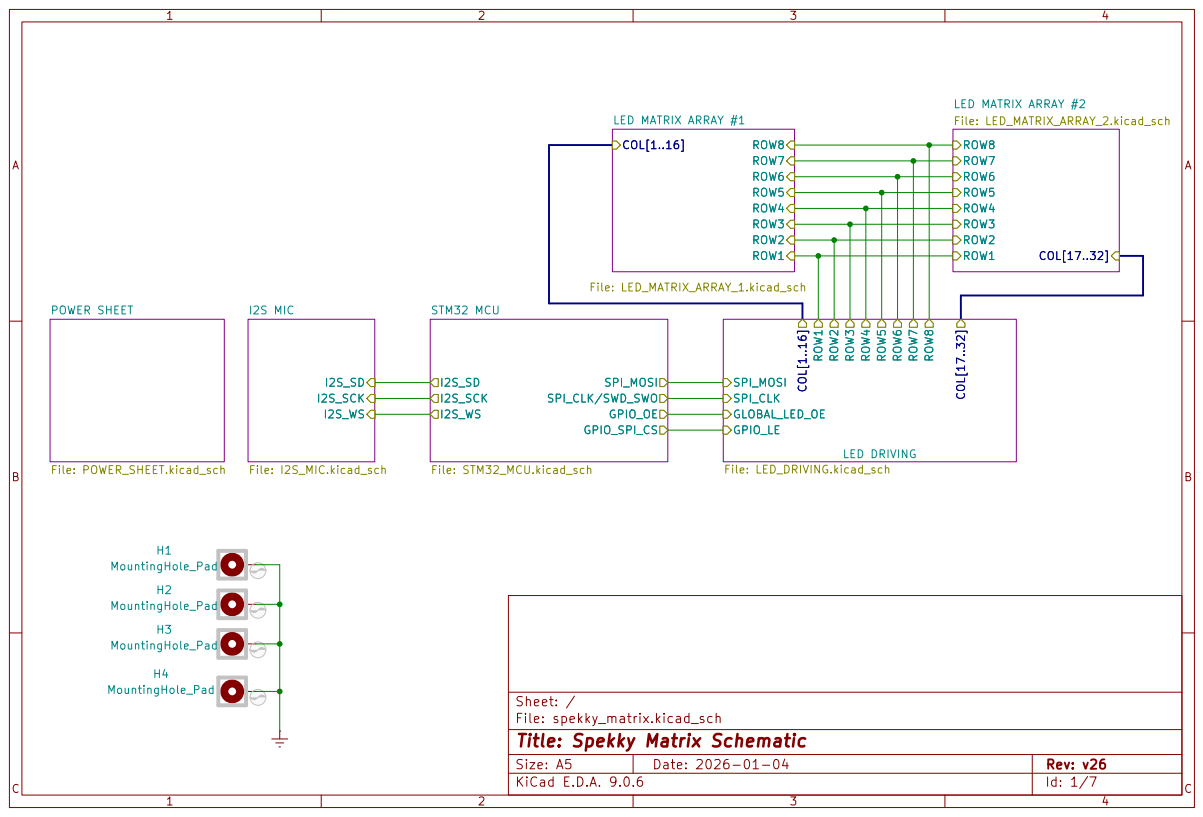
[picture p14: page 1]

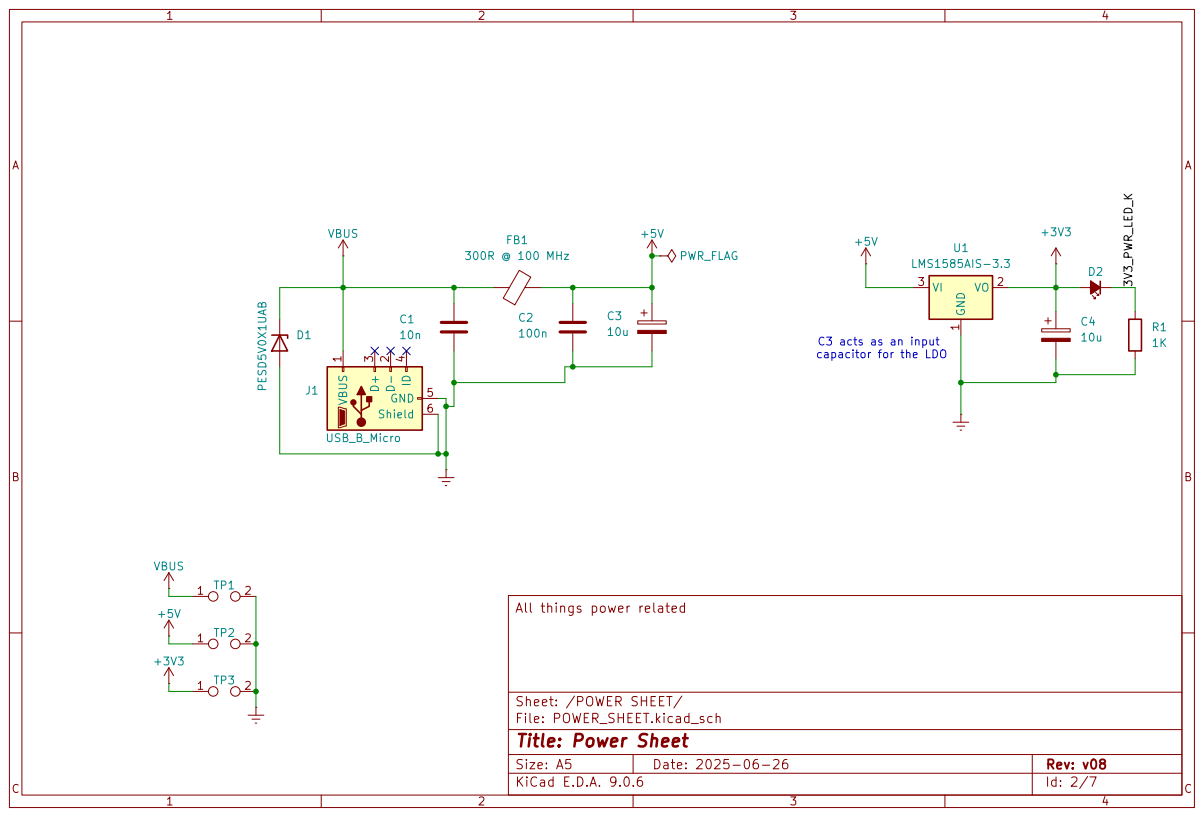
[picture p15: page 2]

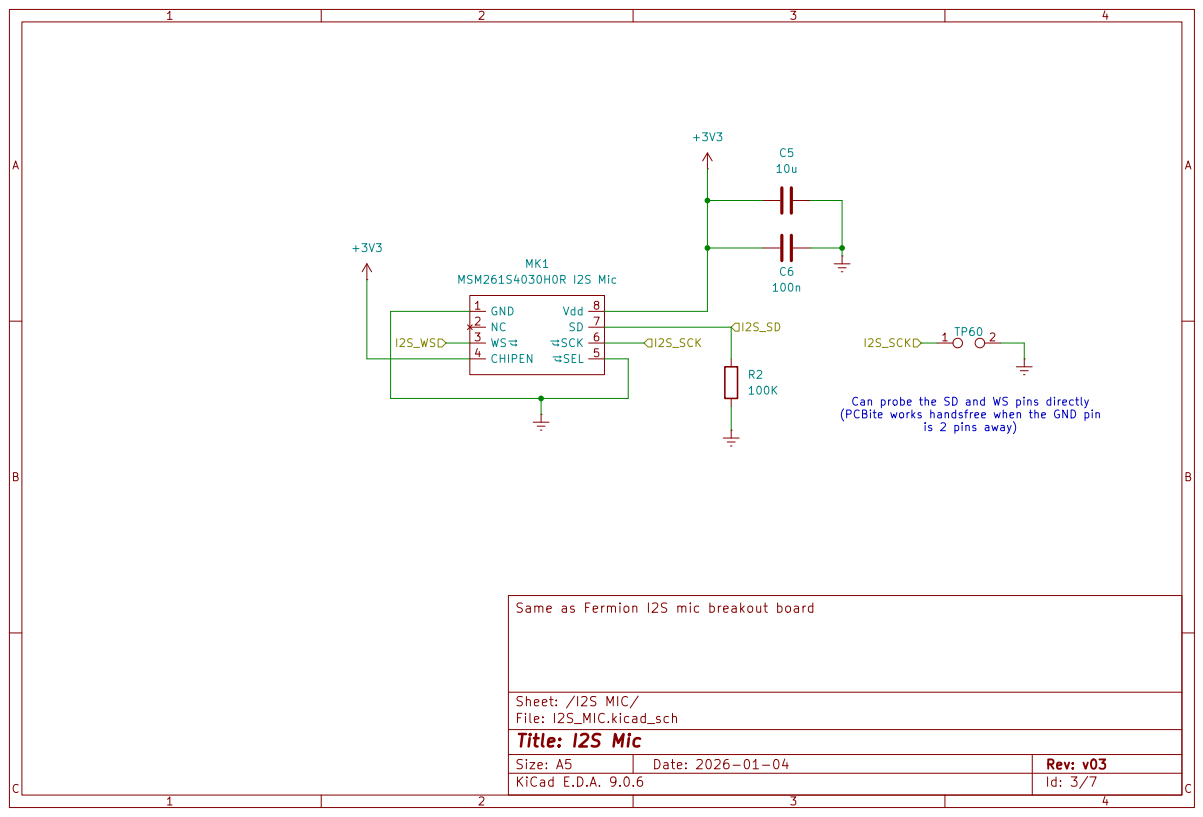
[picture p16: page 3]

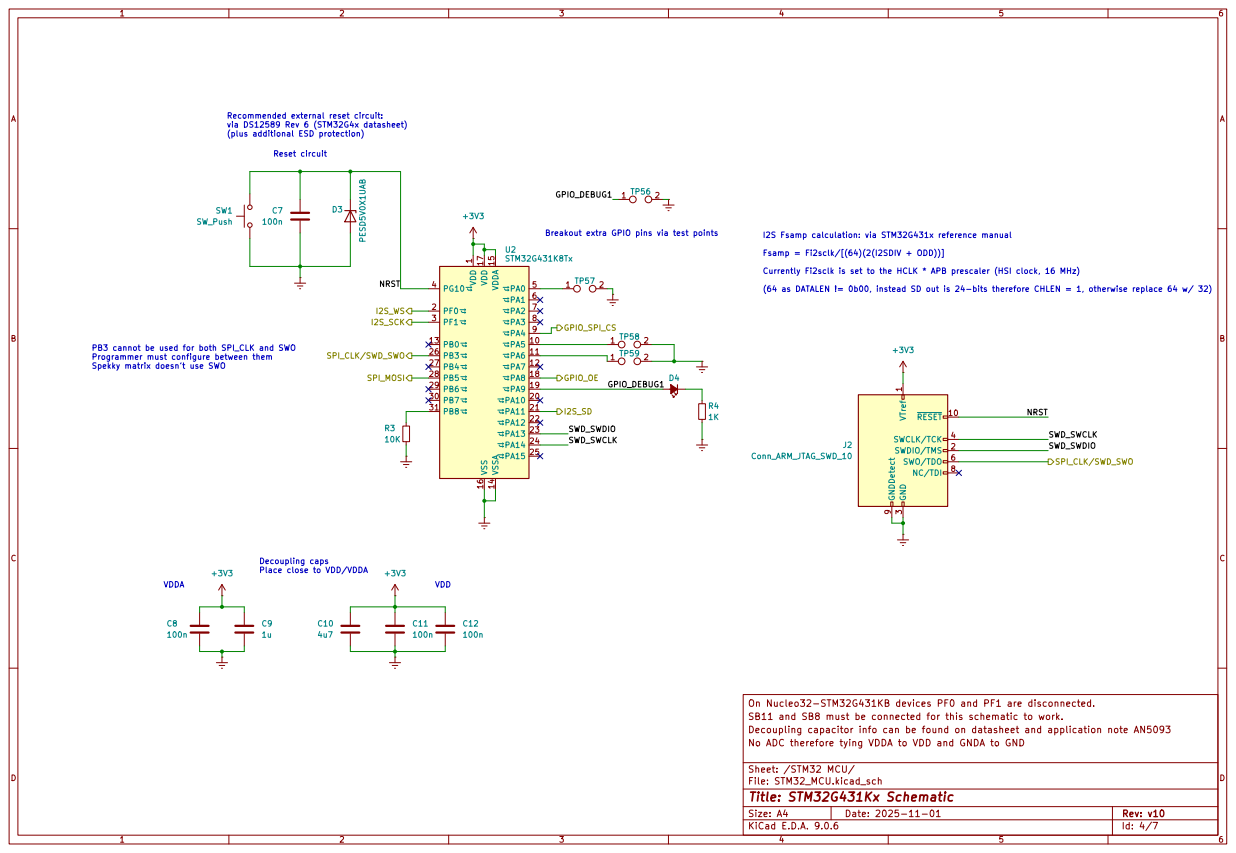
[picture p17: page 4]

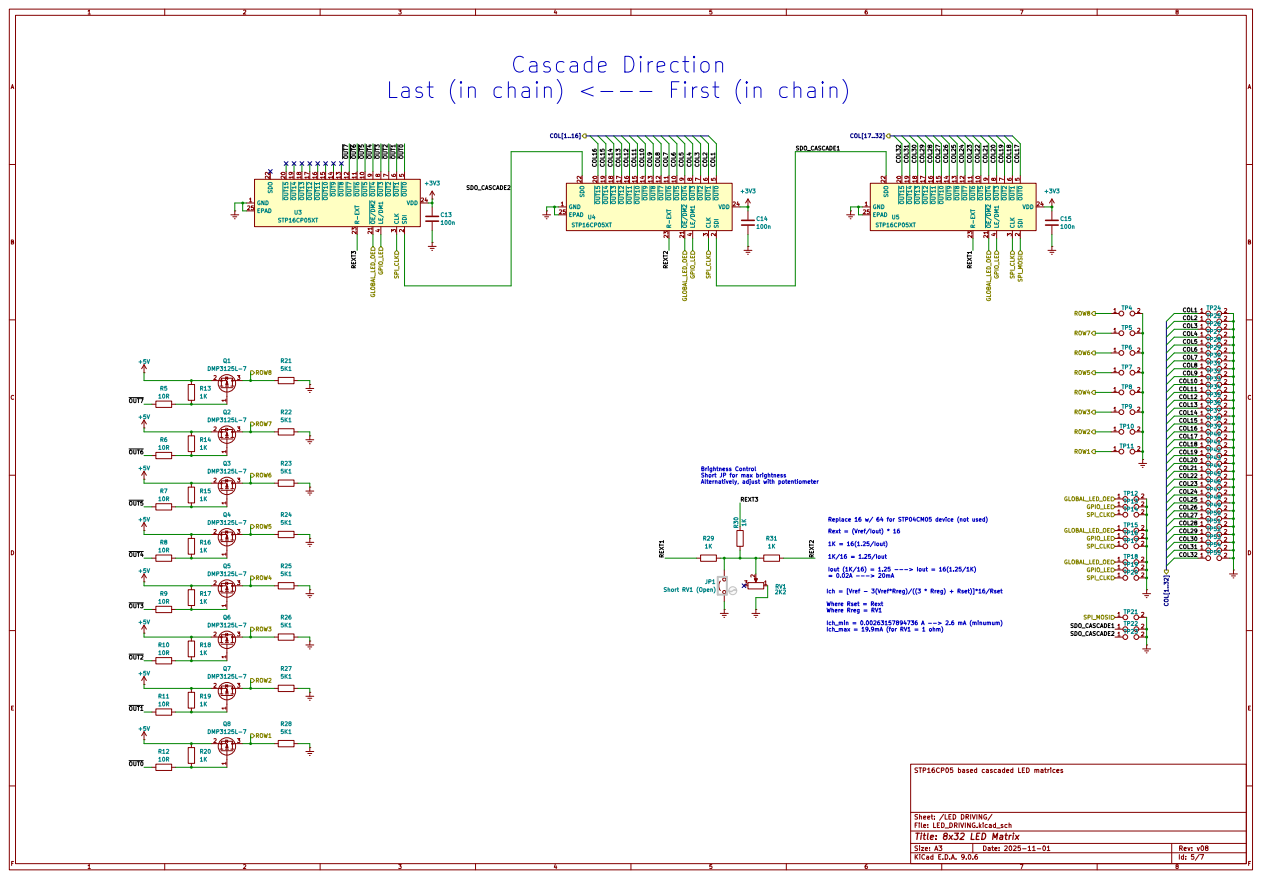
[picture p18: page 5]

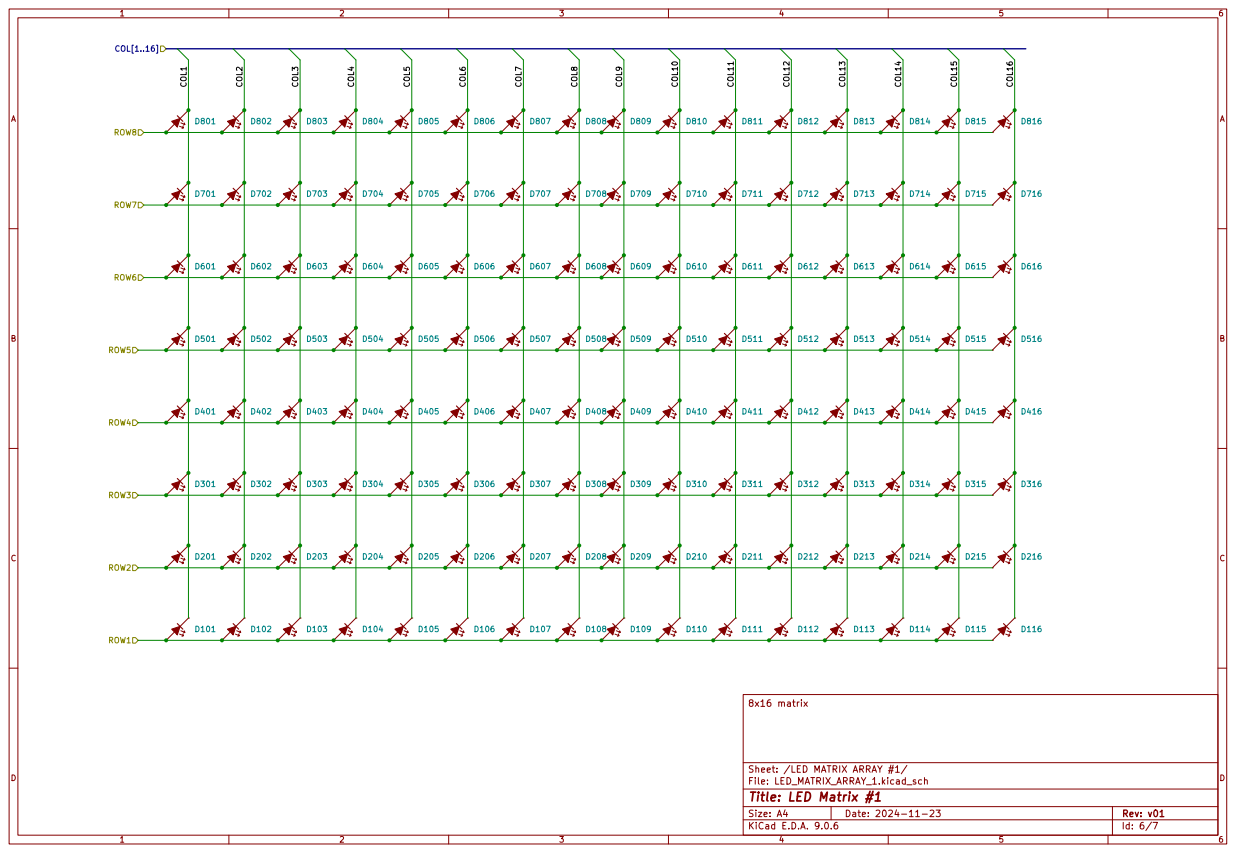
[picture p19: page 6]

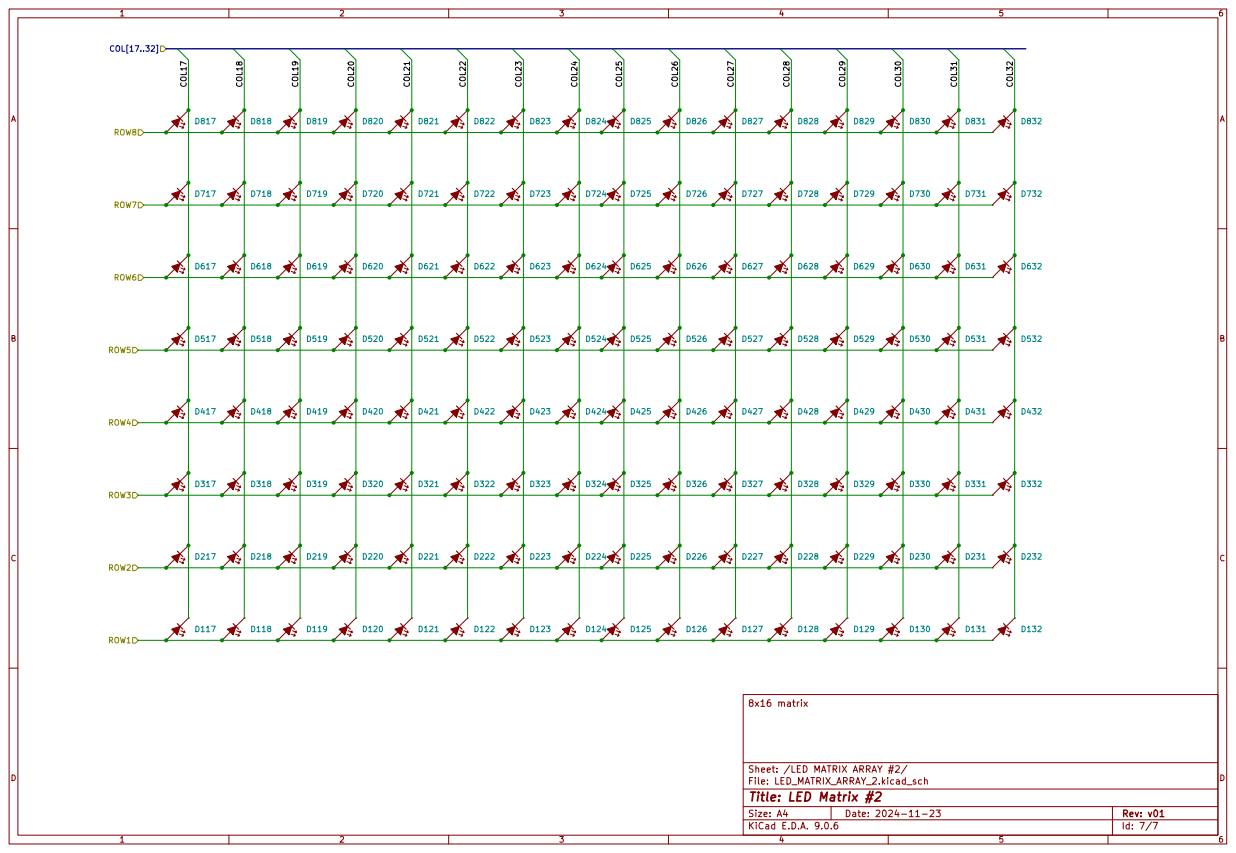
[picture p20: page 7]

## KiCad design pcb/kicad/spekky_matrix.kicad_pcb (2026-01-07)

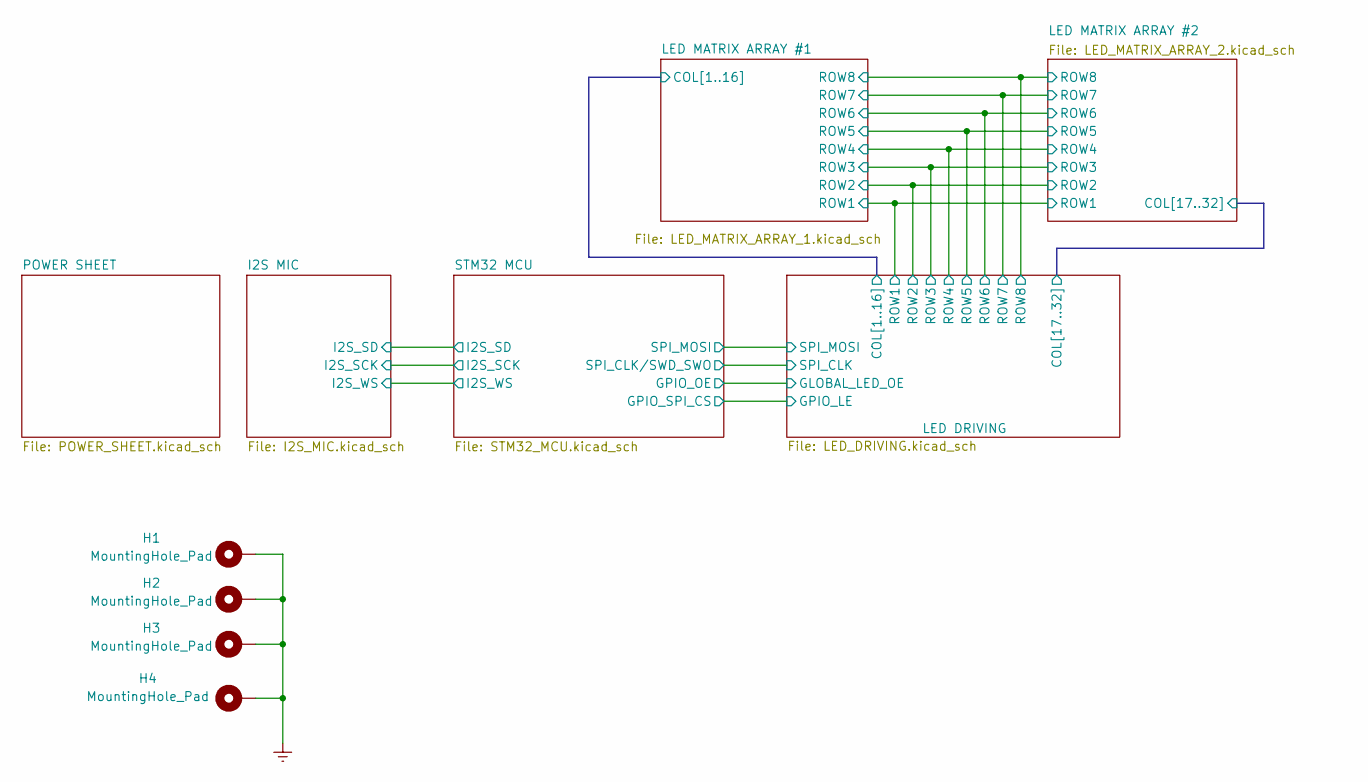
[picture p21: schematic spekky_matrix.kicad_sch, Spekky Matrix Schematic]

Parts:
H1, H2, H3, H4: MountingHole_Pad; MountingHole_3.2mm_M3_Pad

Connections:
GND: H1.1, H2.1, H3.1, H4.1; also elsewhere on the board

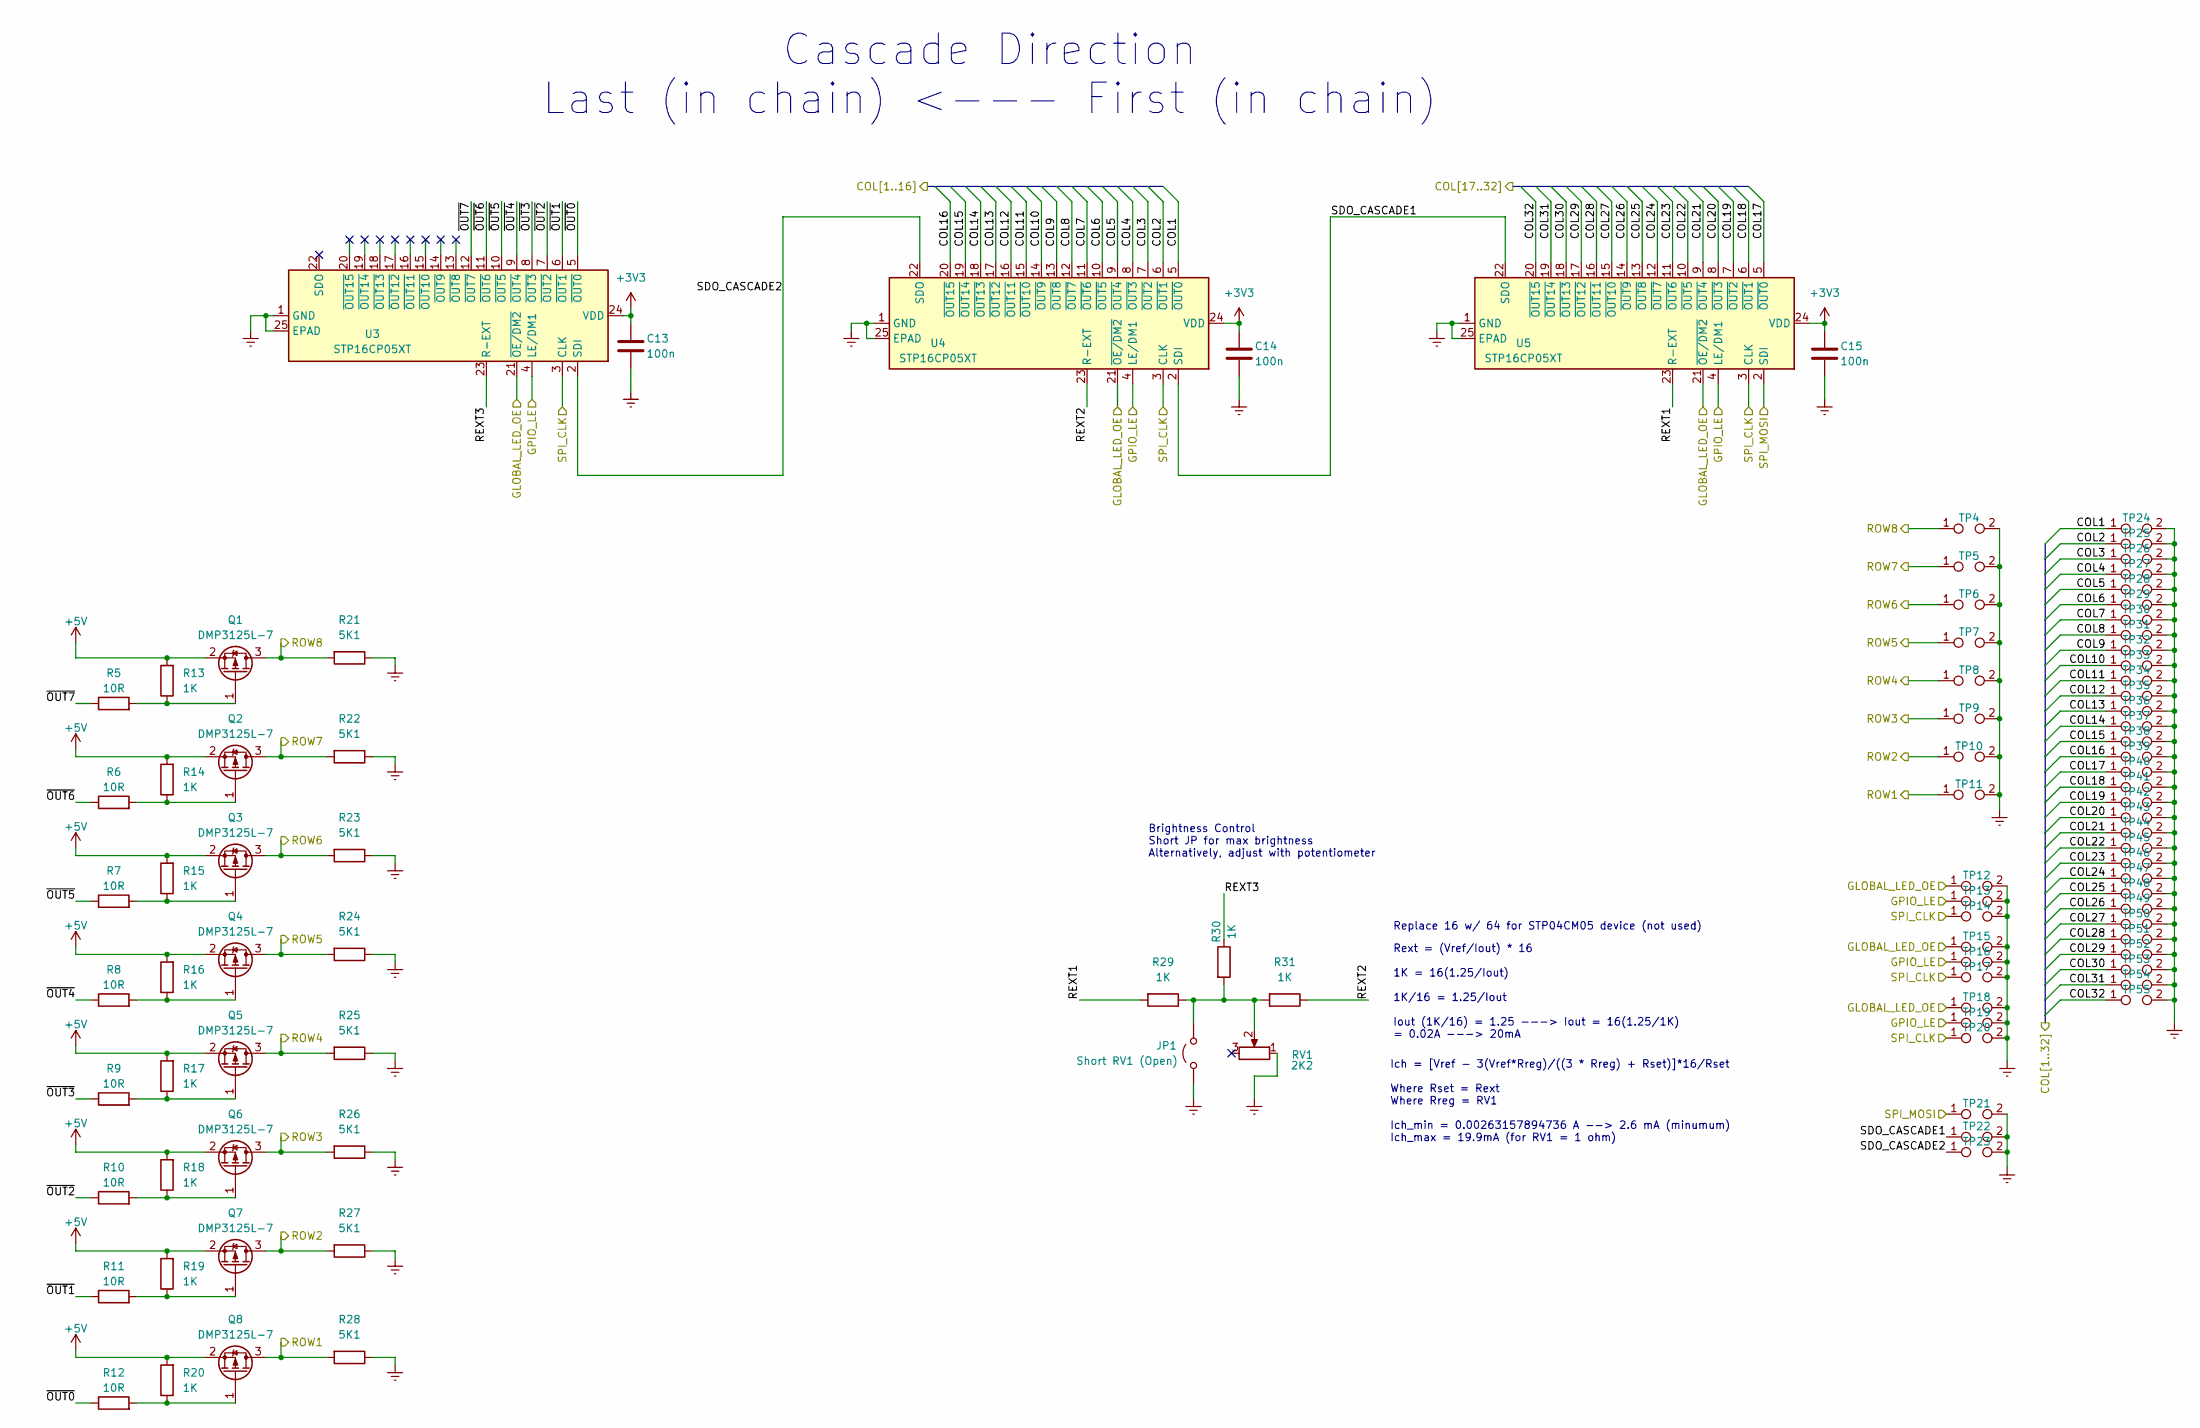
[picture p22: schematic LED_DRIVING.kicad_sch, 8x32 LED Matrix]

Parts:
C13, C14, C15: 100n; C_0603_1608Metric; MPN C0603C104J3RACTU
JP1: Short RV1 (Open); PinHeader_1x02_P2.54mm_Vertical
Q1, Q2, Q3, Q4, Q5, Q6, Q7, Q8: DMP3125L-7; SOT-23; MPN DMP3125L-7
R5, R6, R7, R8, R9, R10, R11, R12: 10R; R_0603_1608Metric; MPN RT0603FRE0710RL
R13, R14, R15, R16, R17, R18, R19, R20, R29, R30, R31: 1K; R_0603_1608Metric; MPN RT0603DRE071KL
R21, R22, R23, R24, R25, R26, R27, R28: 5K1; R_0603_1608Metric; MPN RT0603FRE075K1L
RV1: 2K2; Potentiometer_Bourns_3386F_Vertical; MPN 3386F-1-222LF
TP4, TP5, TP11, TP16, TP24, TP25, TP26, TP27, TP28, TP29, TP30, TP31, TP32, TP33, TP34, TP35, TP36, TP37, TP38, TP39, TP40, TP41, TP42, TP43, TP44, TP45, TP46, TP47, TP48, TP49, TP50, TP51, TP52, TP53, TP54, TP55: TestPoint_2Pole; D_0805_2012Metric
TP6, TP7, TP8, TP9, TP10, TP12, TP13, TP14, TP15, TP17, TP18, TP19, TP20, TP21, TP22, TP23: TestPoint_2Pole; D_MicroMELF
U3, U4, U5: STP16CP05XT; HTSSOP-24-1EP_4.4x7.8mm_P0.65mm_EP3.2x5mm; MPN STP16CP05XTTR

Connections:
+3V3: C13.1, C14.1, C15.1, U3.24 (VDD), U4.24 (VDD), U5.24 (VDD); also elsewhere on the board
+5V: Q1.2 (S), Q2.2 (S), Q3.2 (S), Q4.2 (S), Q5.2 (S), Q6.2 (S), Q7.2 (S), Q8.2 (S), R13.2, R14.2, R15.2, R16.2, R17.2, R18.2, R19.2, R20.2; also elsewhere on the board
/LED DRIVING/COL1: TP24.1, U4.5 (~OUT0); also elsewhere on the board
/LED DRIVING/COL2: TP25.1, U4.6 (~OUT1); also elsewhere on the board
/LED DRIVING/COL3: TP26.1, U4.7 (~OUT2); also elsewhere on the board
/LED DRIVING/COL4: TP27.1, U4.8 (~OUT3); also elsewhere on the board
/LED DRIVING/COL5: TP28.1, U4.9 (~OUT4); also elsewhere on the board
/LED DRIVING/COL6: TP29.1, U4.10 (~OUT5); also elsewhere on the board
/LED DRIVING/COL7: TP30.1, U4.11 (~OUT6); also elsewhere on the board
/LED DRIVING/COL8: TP31.1, U4.12 (~OUT7); also elsewhere on the board
/LED DRIVING/COL9: TP32.1, U4.13 (~OUT8); also elsewhere on the board
/LED DRIVING/COL10: TP33.1, U4.14 (~OUT9); also elsewhere on the board
/LED DRIVING/COL11: TP34.1, U4.15 (~OUT10); also elsewhere on the board
/LED DRIVING/COL12: TP35.1, U4.16 (~OUT11); also elsewhere on the board
/LED DRIVING/COL13: TP36.1, U4.17 (~OUT12); also elsewhere on the board
/LED DRIVING/COL14: TP37.1, U4.18 (~OUT13); also elsewhere on the board
/LED DRIVING/COL15: TP38.1, U4.19 (~OUT14); also elsewhere on the board
/LED DRIVING/COL16: TP39.1, U4.20 (~OUT15); also elsewhere on the board
/LED DRIVING/COL17: TP40.1, U5.5 (~OUT0); also elsewhere on the board
/LED DRIVING/COL18: TP41.1, U5.6 (~OUT1); also elsewhere on the board
/LED DRIVING/COL19: TP42.1, U5.7 (~OUT2); also elsewhere on the board
/LED DRIVING/COL20: TP43.1, U5.8 (~OUT3); also elsewhere on the board
/LED DRIVING/COL21: TP44.1, U5.9 (~OUT4); also elsewhere on the board
/LED DRIVING/COL22: TP45.1, U5.10 (~OUT5); also elsewhere on the board
/LED DRIVING/COL23: TP46.1, U5.11 (~OUT6); also elsewhere on the board
/LED DRIVING/COL24: TP47.1, U5.12 (~OUT7); also elsewhere on the board
/LED DRIVING/COL25: TP48.1, U5.13 (~OUT8); also elsewhere on the board
/LED DRIVING/COL26: TP49.1, U5.14 (~OUT9); also elsewhere on the board
/LED DRIVING/COL27: TP50.1, U5.15 (~OUT10); also elsewhere on the board
/LED DRIVING/COL28: TP51.1, U5.16 (~OUT11); also elsewhere on the board
/LED DRIVING/COL29: TP52.1, U5.17 (~OUT12); also elsewhere on the board
/LED DRIVING/COL30: TP53.1, U5.18 (~OUT13); also elsewhere on the board
/LED DRIVING/COL31: TP54.1, U5.19 (~OUT14); also elsewhere on the board
/LED DRIVING/COL32: TP55.1, U5.20 (~OUT15); also elsewhere on the board
/LED DRIVING/GLOBAL_LED_OE: TP12.1, TP15.1, TP18.1, U3.21 (~OE/DM2), U4.21 (~OE/DM2), U5.21 (~OE/DM2); also elsewhere on the board
/LED DRIVING/GPIO_LE: TP13.1, TP16.1, TP19.1, U3.4 (LE/DM1), U4.4 (LE/DM1), U5.4 (LE/DM1); also elsewhere on the board
/LED DRIVING/REXT1: R29.2, U5.23 (R-EXT)
/LED DRIVING/REXT2: R31.1, U4.23 (R-EXT)
/LED DRIVING/REXT3: R30.1, U3.23 (R-EXT)
/LED DRIVING/ROW1: Q8.3 (D), R28.2, TP11.1; also elsewhere on the board
/LED DRIVING/ROW2: Q7.3 (D), R27.2, TP10.1; also elsewhere on the board
/LED DRIVING/ROW3: Q6.3 (D), R26.2, TP9.1; also elsewhere on the board
/LED DRIVING/ROW4: Q5.3 (D), R25.2, TP8.1; also elsewhere on the board
/LED DRIVING/ROW5: Q4.3 (D), R24.2, TP7.1; also elsewhere on the board
/LED DRIVING/ROW6: Q3.3 (D), R23.2, TP6.1; also elsewhere on the board
/LED DRIVING/ROW7: Q2.3 (D), R22.2, TP5.1; also elsewhere on the board
/LED DRIVING/ROW8: Q1.3 (D), R21.2, TP4.1; also elsewhere on the board
/LED DRIVING/SDO_CASCADE1: TP22.1, U4.2 (SDI), U5.22 (SDO)
/LED DRIVING/SDO_CASCADE2: TP23.1, U3.2 (SDI), U4.22 (SDO)
/LED DRIVING/SPI_CLK: TP14.1, TP17.1, TP20.1, U3.3 (CLK), U4.3 (CLK), U5.3 (CLK); also elsewhere on the board
/LED DRIVING/SPI_MOSI: TP21.1, U5.2 (SDI); also elsewhere on the board
/LED DRIVING/~OUT0: R12.1, U3.5 (~OUT0)
/LED DRIVING/~OUT1: R11.1, U3.6 (~OUT1)
/LED DRIVING/~OUT2: R10.1, U3.7 (~OUT2)
/LED DRIVING/~OUT3: R9.1, U3.8 (~OUT3)
/LED DRIVING/~OUT4: R8.1, U3.9 (~OUT4)
/LED DRIVING/~OUT5: R7.1, U3.10 (~OUT5)
/LED DRIVING/~OUT6: R6.1, U3.11 (~OUT6)
/LED DRIVING/~OUT7: R5.1, U3.12 (~OUT7)
GND: C13.2, C14.2, C15.2, JP1.1 (A), R21.1, R22.1, R23.1, R24.1, R25.1, R26.1, R27.1, R28.1, RV1.1, TP4.2, TP5.2, TP6.2, TP7.2, TP8.2, TP9.2, TP10.2, TP11.2, TP12.2, TP13.2, TP14.2, TP15.2, TP16.2, TP17.2, TP18.2, TP19.2, TP20.2, TP21.2, TP22.2, TP23.2, TP24.2, TP25.2, TP26.2, TP27.2, TP28.2, TP29.2, TP30.2, TP31.2, TP32.2, TP33.2, TP34.2, TP35.2, TP36.2, TP37.2, TP38.2, TP39.2, TP40.2, TP41.2, TP42.2, TP43.2, TP44.2, TP45.2, TP46.2, TP47.2, TP48.2, TP49.2, TP50.2, TP51.2, TP52.2, TP53.2, TP54.2, TP55.2, U3.1 (GND), U3.25 (EPAD), U4.1 (GND), U4.25 (EPAD), U5.1 (GND), U5.25 (EPAD); also elsewhere on the board
unnamed: JP1.2 (B), R29.1, R30.2, R31.2, RV1.2
unnamed: Q1.1 (G), R5.2, R13.1
unnamed: Q2.1 (G), R6.2, R14.1
unnamed: Q3.1 (G), R7.2, R15.1
unnamed: Q4.1 (G), R8.2, R16.1
unnamed: Q5.1 (G), R9.2, R17.1
unnamed: Q6.1 (G), R10.2, R18.1
unnamed: Q7.1 (G), R11.2, R19.1
unnamed: Q8.1 (G), R12.2, R20.1

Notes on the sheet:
Rext = (Vref/Iout) * 16 1K = 16(1.25/Iout) 1K/16 = 1.25/Iout Iout (1K/16) = 1.25 ---> Iout = 16(1.25/1K) = 0.02A ---> 20mA
Cascade Direction Last (in chain) <--- First (in chain)
Brightness Control Short JP for max brightness Alternatively, adjust with potentiometer
Ich = [Vref - 3(Vref*Rreg)/((3 * Rreg) + Rset)]*16/Rset Where Rset = Rext Where Rreg = RV1 Ich_min = 0.00263157894736 A --> 2.6 mA (minumum) Ich_max = 19.9mA (for RV1 = 1 ohm)
Replace 16 w/ 64 for STP04CM05 device (not used)

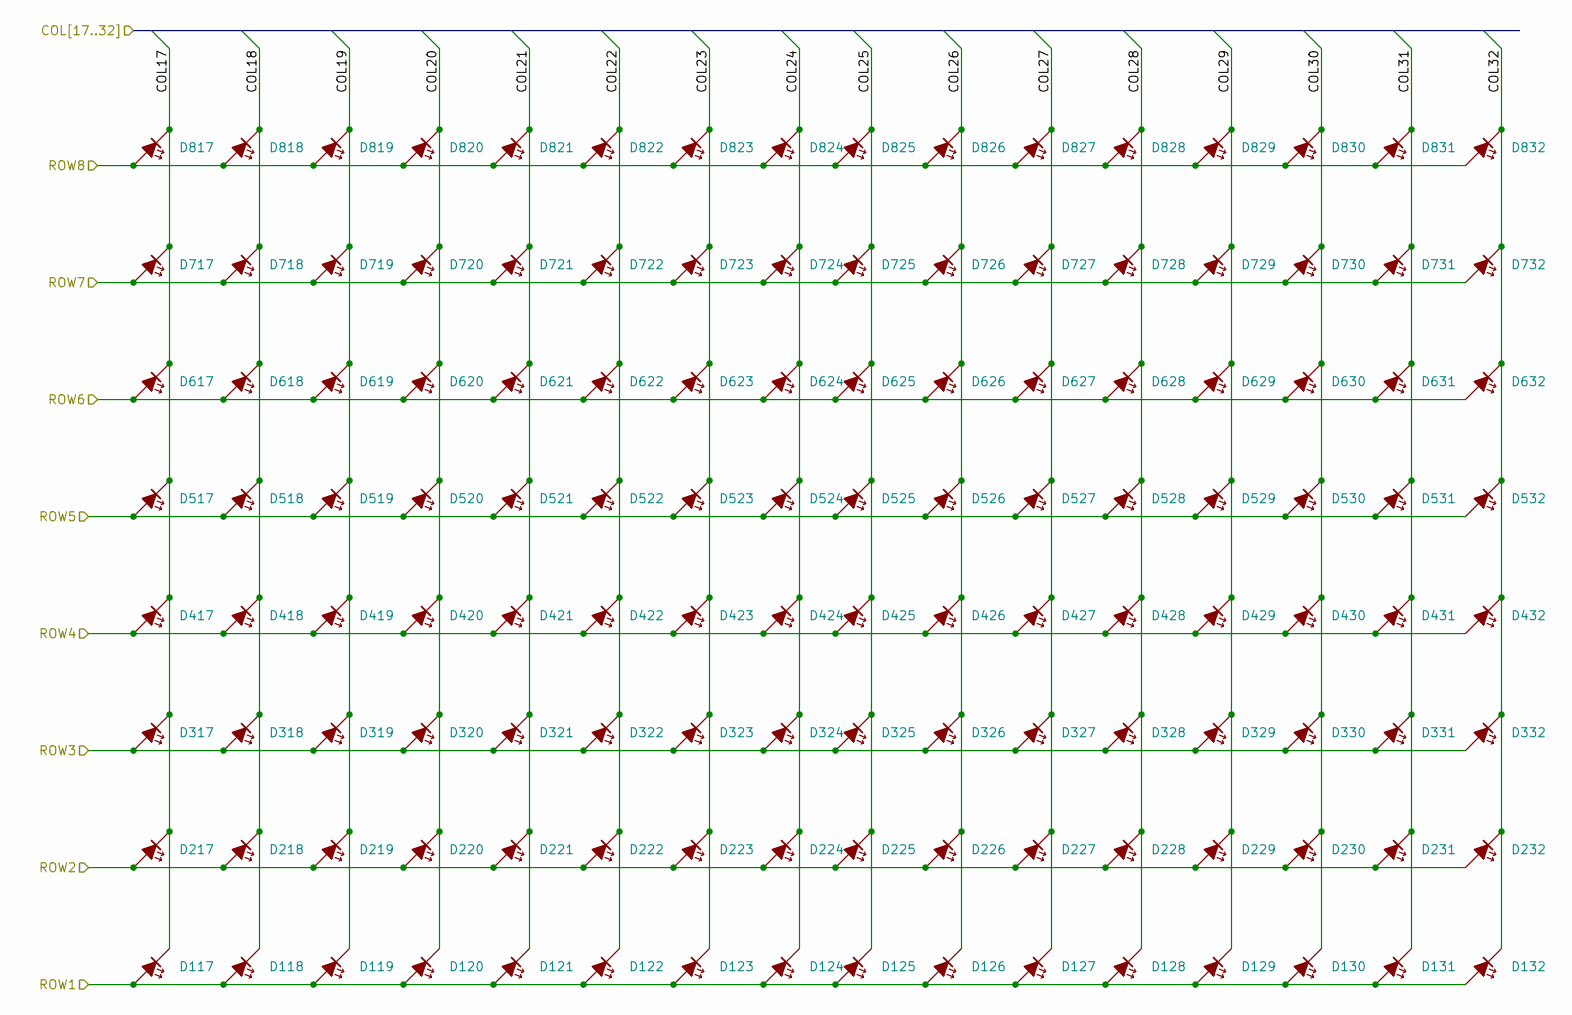
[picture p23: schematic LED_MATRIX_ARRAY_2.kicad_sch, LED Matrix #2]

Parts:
D117, D118, D119, D120, D121, D122, D123, D124, D125, D126, D127, D128, D129, D130, D131, D132, D217, D218, D219, D220, D221, D222, D223, D224, D225, D226, D227, D228, D229, D230, D231, D232, D317, D318, D319, D320, D321, D322, D323, D324, D325, D326, D327, D328, D329, D330, D331, D332, D417, D418, D419, D420, D421, D422, D423, D424, D425, D426, D427, D428, D429, D430, D431, D432, D517, D518, D519, D520, D521, D522, D523, D524, D525, D526, D527, D528, D529, D530, D531, D532, D617, D618, D619, D620, D621, D622, D623, D624, D625, D626, D627, D628, D629, D630, D631, D632, D717, D718, D719, D720, D721, D722, D723, D724, D725, D726, D727, D728, D729, D730, D731, D732, D817, D818, D819, D820, D821, D822, D823, D824, D825, D826, D827, D828, D829, D830, D831, D832: LED Matrix (RED); LED_0603_1608Metric_Pad1.05x0.95mm_HandSolder; MPN LTST-C190KRKT

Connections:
/LED DRIVING/COL17: D117.1 (K), D217.1 (K), D317.1 (K), D417.1 (K), D517.1 (K), D617.1 (K), D717.1 (K), D817.1 (K); also elsewhere on the board
/LED DRIVING/COL18: D118.1 (K), D218.1 (K), D318.1 (K), D418.1 (K), D518.1 (K), D618.1 (K), D718.1 (K), D818.1 (K); also elsewhere on the board
/LED DRIVING/COL19: D119.1 (K), D219.1 (K), D319.1 (K), D419.1 (K), D519.1 (K), D619.1 (K), D719.1 (K), D819.1 (K); also elsewhere on the board
/LED DRIVING/COL20: D120.1 (K), D220.1 (K), D320.1 (K), D420.1 (K), D520.1 (K), D620.1 (K), D720.1 (K), D820.1 (K); also elsewhere on the board
/LED DRIVING/COL21: D121.1 (K), D221.1 (K), D321.1 (K), D421.1 (K), D521.1 (K), D621.1 (K), D721.1 (K), D821.1 (K); also elsewhere on the board
/LED DRIVING/COL22: D122.1 (K), D222.1 (K), D322.1 (K), D422.1 (K), D522.1 (K), D622.1 (K), D722.1 (K), D822.1 (K); also elsewhere on the board
/LED DRIVING/COL23: D123.1 (K), D223.1 (K), D323.1 (K), D423.1 (K), D523.1 (K), D623.1 (K), D723.1 (K), D823.1 (K); also elsewhere on the board
/LED DRIVING/COL24: D124.1 (K), D224.1 (K), D324.1 (K), D424.1 (K), D524.1 (K), D624.1 (K), D724.1 (K), D824.1 (K); also elsewhere on the board
/LED DRIVING/COL25: D125.1 (K), D225.1 (K), D325.1 (K), D425.1 (K), D525.1 (K), D625.1 (K), D725.1 (K), D825.1 (K); also elsewhere on the board
/LED DRIVING/COL26: D126.1 (K), D226.1 (K), D326.1 (K), D426.1 (K), D526.1 (K), D626.1 (K), D726.1 (K), D826.1 (K); also elsewhere on the board
/LED DRIVING/COL27: D127.1 (K), D227.1 (K), D327.1 (K), D427.1 (K), D527.1 (K), D627.1 (K), D727.1 (K), D827.1 (K); also elsewhere on the board
/LED DRIVING/COL28: D128.1 (K), D228.1 (K), D328.1 (K), D428.1 (K), D528.1 (K), D628.1 (K), D728.1 (K), D828.1 (K); also elsewhere on the board
/LED DRIVING/COL29: D129.1 (K), D229.1 (K), D329.1 (K), D429.1 (K), D529.1 (K), D629.1 (K), D729.1 (K), D829.1 (K); also elsewhere on the board
/LED DRIVING/COL30: D130.1 (K), D230.1 (K), D330.1 (K), D430.1 (K), D530.1 (K), D630.1 (K), D730.1 (K), D830.1 (K); also elsewhere on the board
/LED DRIVING/COL31: D131.1 (K), D231.1 (K), D331.1 (K), D431.1 (K), D531.1 (K), D631.1 (K), D731.1 (K), D831.1 (K); also elsewhere on the board
/LED DRIVING/COL32: D132.1 (K), D232.1 (K), D332.1 (K), D432.1 (K), D532.1 (K), D632.1 (K), D732.1 (K), D832.1 (K); also elsewhere on the board
/LED DRIVING/ROW1: D117.2 (A), D118.2 (A), D119.2 (A), D120.2 (A), D121.2 (A), D122.2 (A), D123.2 (A), D124.2 (A), D125.2 (A), D126.2 (A), D127.2 (A), D128.2 (A), D129.2 (A), D130.2 (A), D131.2 (A), D132.2 (A); also elsewhere on the board
/LED DRIVING/ROW2: D217.2 (A), D218.2 (A), D219.2 (A), D220.2 (A), D221.2 (A), D222.2 (A), D223.2 (A), D224.2 (A), D225.2 (A), D226.2 (A), D227.2 (A), D228.2 (A), D229.2 (A), D230.2 (A), D231.2 (A), D232.2 (A); also elsewhere on the board
/LED DRIVING/ROW3: D317.2 (A), D318.2 (A), D319.2 (A), D320.2 (A), D321.2 (A), D322.2 (A), D323.2 (A), D324.2 (A), D325.2 (A), D326.2 (A), D327.2 (A), D328.2 (A), D329.2 (A), D330.2 (A), D331.2 (A), D332.2 (A); also elsewhere on the board
/LED DRIVING/ROW4: D417.2 (A), D418.2 (A), D419.2 (A), D420.2 (A), D421.2 (A), D422.2 (A), D423.2 (A), D424.2 (A), D425.2 (A), D426.2 (A), D427.2 (A), D428.2 (A), D429.2 (A), D430.2 (A), D431.2 (A), D432.2 (A); also elsewhere on the board
/LED DRIVING/ROW5: D517.2 (A), D518.2 (A), D519.2 (A), D520.2 (A), D521.2 (A), D522.2 (A), D523.2 (A), D524.2 (A), D525.2 (A), D526.2 (A), D527.2 (A), D528.2 (A), D529.2 (A), D530.2 (A), D531.2 (A), D532.2 (A); also elsewhere on the board
/LED DRIVING/ROW6: D617.2 (A), D618.2 (A), D619.2 (A), D620.2 (A), D621.2 (A), D622.2 (A), D623.2 (A), D624.2 (A), D625.2 (A), D626.2 (A), D627.2 (A), D628.2 (A), D629.2 (A), D630.2 (A), D631.2 (A), D632.2 (A); also elsewhere on the board
/LED DRIVING/ROW7: D717.2 (A), D718.2 (A), D719.2 (A), D720.2 (A), D721.2 (A), D722.2 (A), D723.2 (A), D724.2 (A), D725.2 (A), D726.2 (A), D727.2 (A), D728.2 (A), D729.2 (A), D730.2 (A), D731.2 (A), D732.2 (A); also elsewhere on the board
/LED DRIVING/ROW8: D817.2 (A), D818.2 (A), D819.2 (A), D820.2 (A), D821.2 (A), D822.2 (A), D823.2 (A), D824.2 (A), D825.2 (A), D826.2 (A), D827.2 (A), D828.2 (A), D829.2 (A), D830.2 (A), D831.2 (A), D832.2 (A); also elsewhere on the board

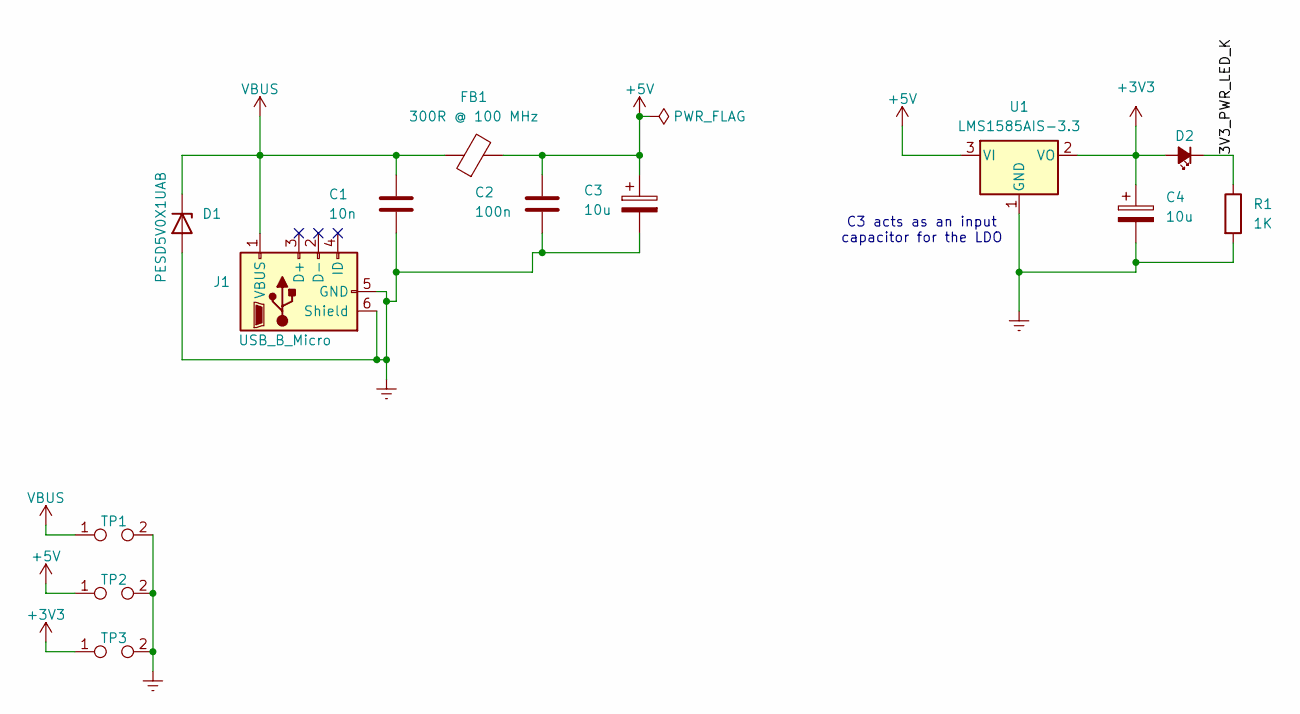
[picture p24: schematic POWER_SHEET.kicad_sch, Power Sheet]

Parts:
C1: 10n; C_0603_1608Metric; MPN GCM188R71H103KA37J
C2: 100n; C_0603_1608Metric; MPN C0603C104J3RACTU
C3, C4: 10u; CP_Elec_4x4.5; MPN EDH106M016A9BAA
D1: PESD5V0X1UAB; D_SOD-523; MPN PESD5V0X1UAB,115
D2: 3V3 LED (RED); LED_0603_1608Metric_Pad1.05x0.95mm_HandSolder; MPN LTST-C190KRKT
FB1: 300R @ 100 MHz; L_0603_1608Metric; MPN HI2220R301R-10
J1: USB_B_Micro; USB_Micro-B_Amphenol_10118194-0001LF_Horizontal; MPN 10118194-0001LF
R1: 1K; R_0603_1608Metric; MPN RT0603DRE071KL
TP1, TP3: TestPoint_2Pole; D_MicroMELF
TP2: TestPoint_2Pole; D_0805_2012Metric
U1: LMS1585AIS-3.3; TO-263-3_TabPin2; MPN LMS1585AIS-3.3/NOPB

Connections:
+3V3: C4.1, D2.2 (A), TP3.1, U1.2 (VO); also elsewhere on the board
+5V: C2.1, C3.1, FB1.2, TP2.1, U1.3 (VI); also elsewhere on the board
/POWER SHEET/3V3_PWR_LED_K: D2.1 (K), R1.1
GND: C1.2, C2.2, C3.2, C4.2, D1.2 (A), J1.5 (GND), J1.6 (Shield), R1.2, TP1.2, TP2.2, TP3.2, U1.1 (GND); also elsewhere on the board
VBUS: C1.1, D1.1 (K), FB1.1, J1.1 (VBUS), TP1.1

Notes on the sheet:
C3 acts as an input capacitor for the LDO

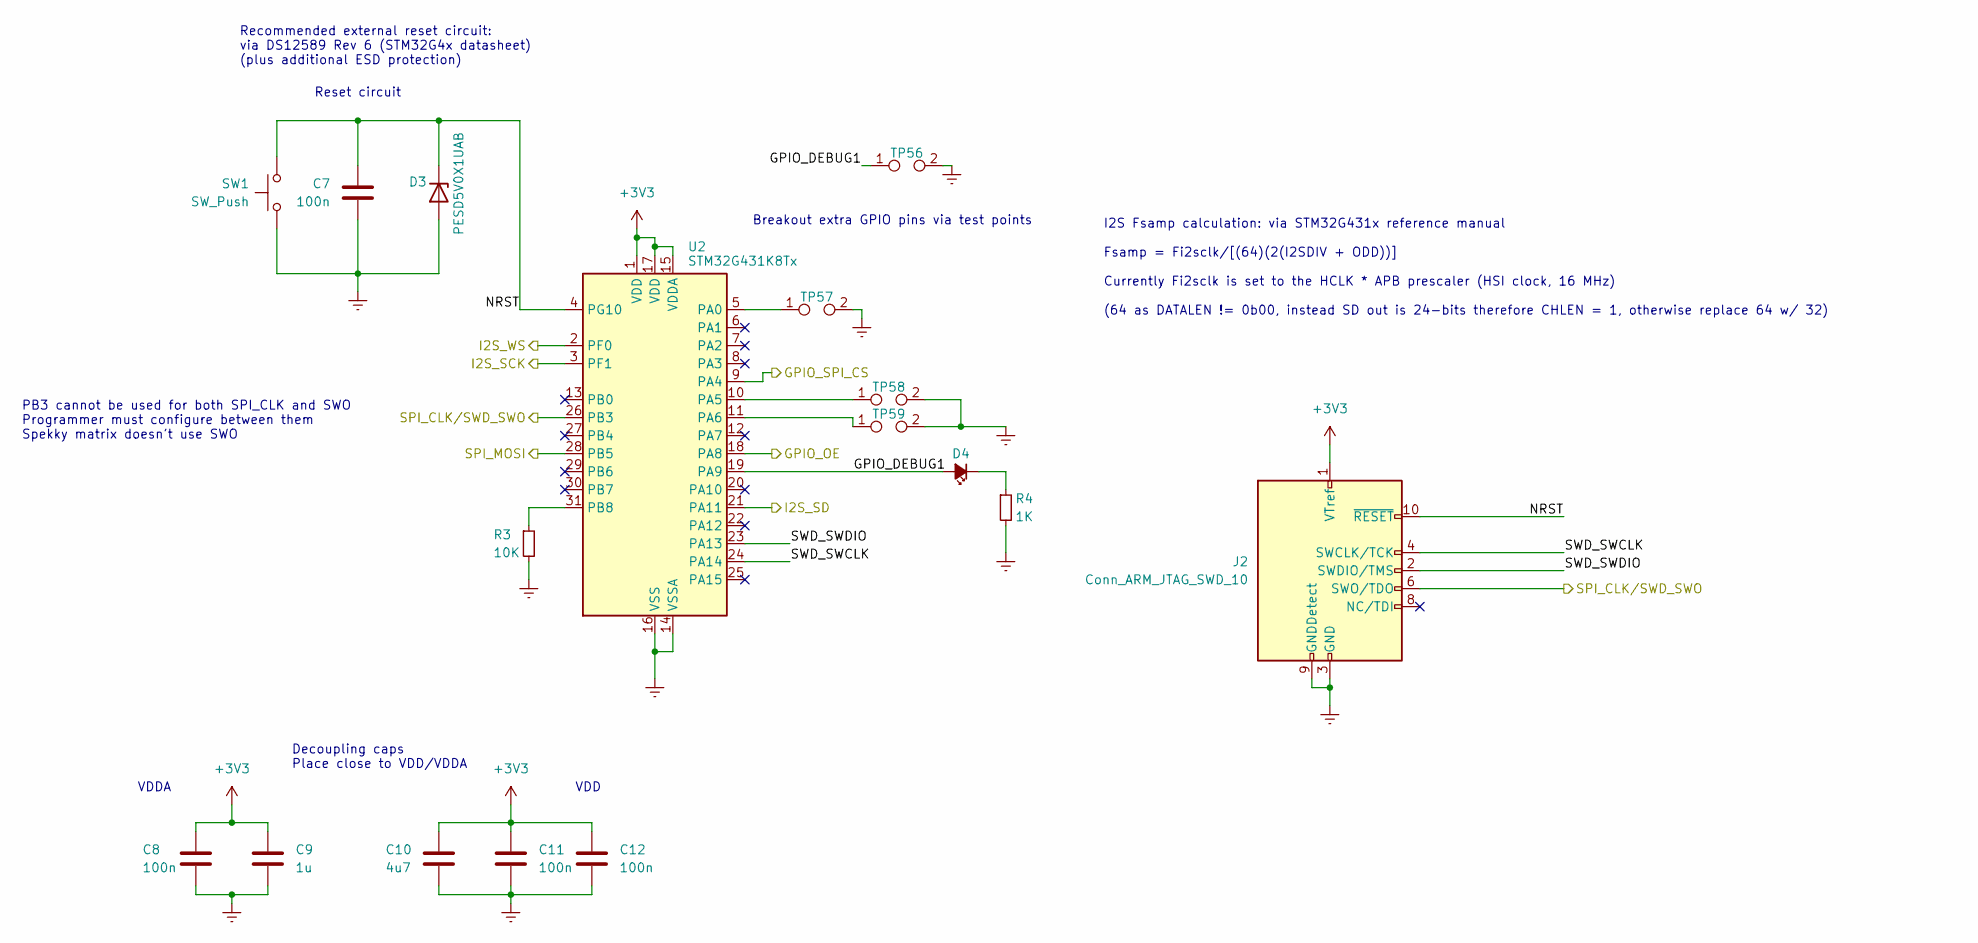
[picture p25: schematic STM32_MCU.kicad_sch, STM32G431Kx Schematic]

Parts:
C7, C8, C11, C12: 100n; C_0603_1608Metric; MPN C0603C104J3RACTU
C9: 1u; C_0603_1608Metric; MPN GCG188L8EE105KA07D
C10: 4u7; C_0603_1608Metric; MPN GRM188Z71C475KE21D
D3: PESD5V0X1UAB; D_SOD-523; MPN PESD5V0X1UAB,115
D4: GPIO Debug LED (GREEN); LED_0603_1608Metric_Pad1.05x0.95mm_HandSolder; MPN LTST-C190KGKT
J2: Conn_ARM_JTAG_SWD_10; PinHeader_2x05_P1.27mm_Vertical; MPN FTSH-105-01-L-D-K
R3: 10K; R_0603_1608Metric; MPN RT0603FRE0710KL
R4: 1K; R_0603_1608Metric; MPN RT0603DRE071KL
SW1: SW_Push; SW_SPST_TL3305A; MPN TL3305AF260QG
TP56, TP57, TP58, TP59: TestPoint_2Pole; D_MicroMELF
U2: STM32G431K8Tx; LQFP-32_7x7mm_P0.8mm; MPN STM32G431K8T6

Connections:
+3V3: C8.1, C9.1, C10.1, C11.1, C12.1, J2.1 (VTref), U2.1 (VDD), U2.15 (VDDA), U2.17 (VDD); also elsewhere on the board
/I2S MIC/I2S_SCK: U2.3 (PF1); also elsewhere on the board
/I2S MIC/I2S_SD: U2.21 (PA11); also elsewhere on the board
/I2S MIC/I2S_WS: U2.2 (PF0); also elsewhere on the board
/LED DRIVING/GLOBAL_LED_OE: U2.18 (PA8); also elsewhere on the board
/LED DRIVING/GPIO_LE: U2.9 (PA4); also elsewhere on the board
/LED DRIVING/SPI_CLK: J2.6 (SWO/TDO), U2.26 (PB3); also elsewhere on the board
/LED DRIVING/SPI_MOSI: U2.28 (PB5); also elsewhere on the board
/STM32 MCU/GPIO_DEBUG1: D4.2 (A), TP56.1, U2.19 (PA9)
/STM32 MCU/NRST: C7.2, D3.1 (K), J2.10 (~RESET), SW1.2, U2.4 (PG10)
/STM32 MCU/SWD_SWCLK: J2.4 (SWCLK/TCK), U2.24 (PA14)
/STM32 MCU/SWD_SWDIO: J2.2 (SWDIO/TMS), U2.23 (PA13)
GND: C7.1, C8.2, C9.2, C10.2, C11.2, C12.2, D3.2 (A), J2.3 (GND), J2.5 (GND), J2.9 (GNDDetect), R3.2, R4.2, SW1.1, TP56.2, TP57.2, TP58.2, TP59.2, U2.14 (VSSA), U2.16 (VSS), U2.32 (VSS); also elsewhere on the board
unnamed: D4.1 (K), R4.1
unnamed: TP57.1, U2.5 (PA0)
unnamed: TP58.1, U2.10 (PA5)
unnamed: TP59.1, U2.11 (PA6)
unnamed: R3.1, U2.31 (PB8)

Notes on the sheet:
Decoupling caps Place close to VDD/VDDA
PB3 cannot be used for both SPI_CLK and SWO Programmer must configure between them Spekky matrix doesn't use SWO
Breakout extra GPIO pins via test points
VDD
Recommended external reset circuit: via DS12589 Rev 6 (STM32G4x datasheet) (plus additional ESD protection)
Reset circuit
I2S Fsamp calculation: via STM32G431x reference manual Fsamp = Fi2sclk/[(64)(2(I2SDIV + ODD))] Currently Fi2sclk is set to the HCLK * APB prescaler (HSI clock, 16 MHz) (64 as DATALEN != 0b00, instead SD out is 24-bits therefore CHLEN = 1, otherwise replace 64 w/ 32)
VDDA

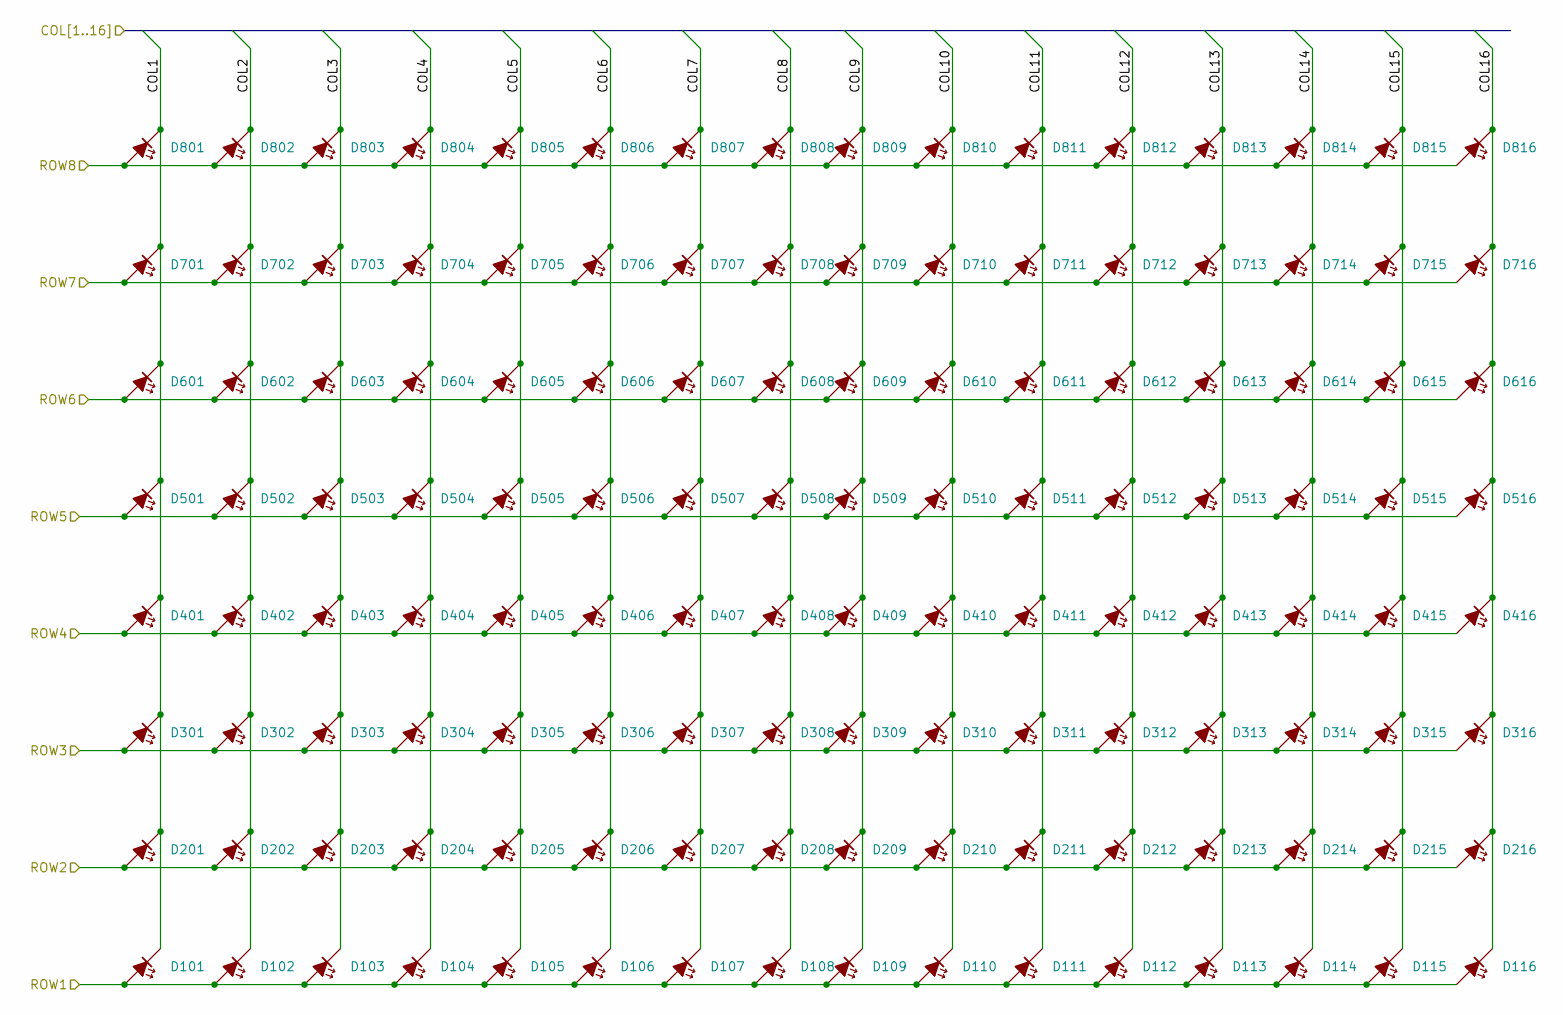
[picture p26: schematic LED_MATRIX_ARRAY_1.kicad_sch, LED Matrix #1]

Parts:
D101, D102, D103, D104, D105, D106, D107, D108, D109, D110, D111, D112, D113, D114, D115, D116, D201, D202, D203, D204, D205, D206, D207, D208, D209, D210, D211, D212, D213, D214, D215, D216, D301, D302, D303, D304, D305, D306, D307, D308, D309, D310, D311, D312, D313, D314, D315, D316, D401, D402, D403, D404, D405, D406, D407, D408, D409, D410, D411, D412, D413, D414, D415, D416, D501, D502, D503, D504, D505, D506, D507, D508, D509, D510, D511, D512, D513, D514, D515, D516, D601, D602, D603, D604, D605, D606, D607, D608, D609, D610, D611, D612, D613, D614, D615, D616, D701, D702, D703, D704, D705, D706, D707, D708, D709, D710, D711, D712, D713, D714, D715, D716, D801, D802, D803, D804, D805, D806, D807, D808, D809, D810, D811, D812, D813, D814, D815, D816: LED Matrix (RED); LED_0603_1608Metric_Pad1.05x0.95mm_HandSolder; MPN LTST-C190KRKT

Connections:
/LED DRIVING/COL1: D101.1 (K), D201.1 (K), D301.1 (K), D401.1 (K), D501.1 (K), D601.1 (K), D701.1 (K), D801.1 (K); also elsewhere on the board
/LED DRIVING/COL2: D102.1 (K), D202.1 (K), D302.1 (K), D402.1 (K), D502.1 (K), D602.1 (K), D702.1 (K), D802.1 (K); also elsewhere on the board
/LED DRIVING/COL3: D103.1 (K), D203.1 (K), D303.1 (K), D403.1 (K), D503.1 (K), D603.1 (K), D703.1 (K), D803.1 (K); also elsewhere on the board
/LED DRIVING/COL4: D104.1 (K), D204.1 (K), D304.1 (K), D404.1 (K), D504.1 (K), D604.1 (K), D704.1 (K), D804.1 (K); also elsewhere on the board
/LED DRIVING/COL5: D105.1 (K), D205.1 (K), D305.1 (K), D405.1 (K), D505.1 (K), D605.1 (K), D705.1 (K), D805.1 (K); also elsewhere on the board
/LED DRIVING/COL6: D106.1 (K), D206.1 (K), D306.1 (K), D406.1 (K), D506.1 (K), D606.1 (K), D706.1 (K), D806.1 (K); also elsewhere on the board
/LED DRIVING/COL7: D107.1 (K), D207.1 (K), D307.1 (K), D407.1 (K), D507.1 (K), D607.1 (K), D707.1 (K), D807.1 (K); also elsewhere on the board
/LED DRIVING/COL8: D108.1 (K), D208.1 (K), D308.1 (K), D408.1 (K), D508.1 (K), D608.1 (K), D708.1 (K), D808.1 (K); also elsewhere on the board
/LED DRIVING/COL9: D109.1 (K), D209.1 (K), D309.1 (K), D409.1 (K), D509.1 (K), D609.1 (K), D709.1 (K), D809.1 (K); also elsewhere on the board
/LED DRIVING/COL10: D110.1 (K), D210.1 (K), D310.1 (K), D410.1 (K), D510.1 (K), D610.1 (K), D710.1 (K), D810.1 (K); also elsewhere on the board
/LED DRIVING/COL11: D111.1 (K), D211.1 (K), D311.1 (K), D411.1 (K), D511.1 (K), D611.1 (K), D711.1 (K), D811.1 (K); also elsewhere on the board
/LED DRIVING/COL12: D112.1 (K), D212.1 (K), D312.1 (K), D412.1 (K), D512.1 (K), D612.1 (K), D712.1 (K), D812.1 (K); also elsewhere on the board
/LED DRIVING/COL13: D113.1 (K), D213.1 (K), D313.1 (K), D413.1 (K), D513.1 (K), D613.1 (K), D713.1 (K), D813.1 (K); also elsewhere on the board
/LED DRIVING/COL14: D114.1 (K), D214.1 (K), D314.1 (K), D414.1 (K), D514.1 (K), D614.1 (K), D714.1 (K), D814.1 (K); also elsewhere on the board
/LED DRIVING/COL15: D115.1 (K), D215.1 (K), D315.1 (K), D415.1 (K), D515.1 (K), D615.1 (K), D715.1 (K), D815.1 (K); also elsewhere on the board
/LED DRIVING/COL16: D116.1 (K), D216.1 (K), D316.1 (K), D416.1 (K), D516.1 (K), D616.1 (K), D716.1 (K), D816.1 (K); also elsewhere on the board
/LED DRIVING/ROW1: D101.2 (A), D102.2 (A), D103.2 (A), D104.2 (A), D105.2 (A), D106.2 (A), D107.2 (A), D108.2 (A), D109.2 (A), D110.2 (A), D111.2 (A), D112.2 (A), D113.2 (A), D114.2 (A), D115.2 (A), D116.2 (A); also elsewhere on the board
/LED DRIVING/ROW2: D201.2 (A), D202.2 (A), D203.2 (A), D204.2 (A), D205.2 (A), D206.2 (A), D207.2 (A), D208.2 (A), D209.2 (A), D210.2 (A), D211.2 (A), D212.2 (A), D213.2 (A), D214.2 (A), D215.2 (A), D216.2 (A); also elsewhere on the board
/LED DRIVING/ROW3: D301.2 (A), D302.2 (A), D303.2 (A), D304.2 (A), D305.2 (A), D306.2 (A), D307.2 (A), D308.2 (A), D309.2 (A), D310.2 (A), D311.2 (A), D312.2 (A), D313.2 (A), D314.2 (A), D315.2 (A), D316.2 (A); also elsewhere on the board
/LED DRIVING/ROW4: D401.2 (A), D402.2 (A), D403.2 (A), D404.2 (A), D405.2 (A), D406.2 (A), D407.2 (A), D408.2 (A), D409.2 (A), D410.2 (A), D411.2 (A), D412.2 (A), D413.2 (A), D414.2 (A), D415.2 (A), D416.2 (A); also elsewhere on the board
/LED DRIVING/ROW5: D501.2 (A), D502.2 (A), D503.2 (A), D504.2 (A), D505.2 (A), D506.2 (A), D507.2 (A), D508.2 (A), D509.2 (A), D510.2 (A), D511.2 (A), D512.2 (A), D513.2 (A), D514.2 (A), D515.2 (A), D516.2 (A); also elsewhere on the board
/LED DRIVING/ROW6: D601.2 (A), D602.2 (A), D603.2 (A), D604.2 (A), D605.2 (A), D606.2 (A), D607.2 (A), D608.2 (A), D609.2 (A), D610.2 (A), D611.2 (A), D612.2 (A), D613.2 (A), D614.2 (A), D615.2 (A), D616.2 (A); also elsewhere on the board
/LED DRIVING/ROW7: D701.2 (A), D702.2 (A), D703.2 (A), D704.2 (A), D705.2 (A), D706.2 (A), D707.2 (A), D708.2 (A), D709.2 (A), D710.2 (A), D711.2 (A), D712.2 (A), D713.2 (A), D714.2 (A), D715.2 (A), D716.2 (A); also elsewhere on the board
/LED DRIVING/ROW8: D801.2 (A), D802.2 (A), D803.2 (A), D804.2 (A), D805.2 (A), D806.2 (A), D807.2 (A), D808.2 (A), D809.2 (A), D810.2 (A), D811.2 (A), D812.2 (A), D813.2 (A), D814.2 (A), D815.2 (A), D816.2 (A); also elsewhere on the board

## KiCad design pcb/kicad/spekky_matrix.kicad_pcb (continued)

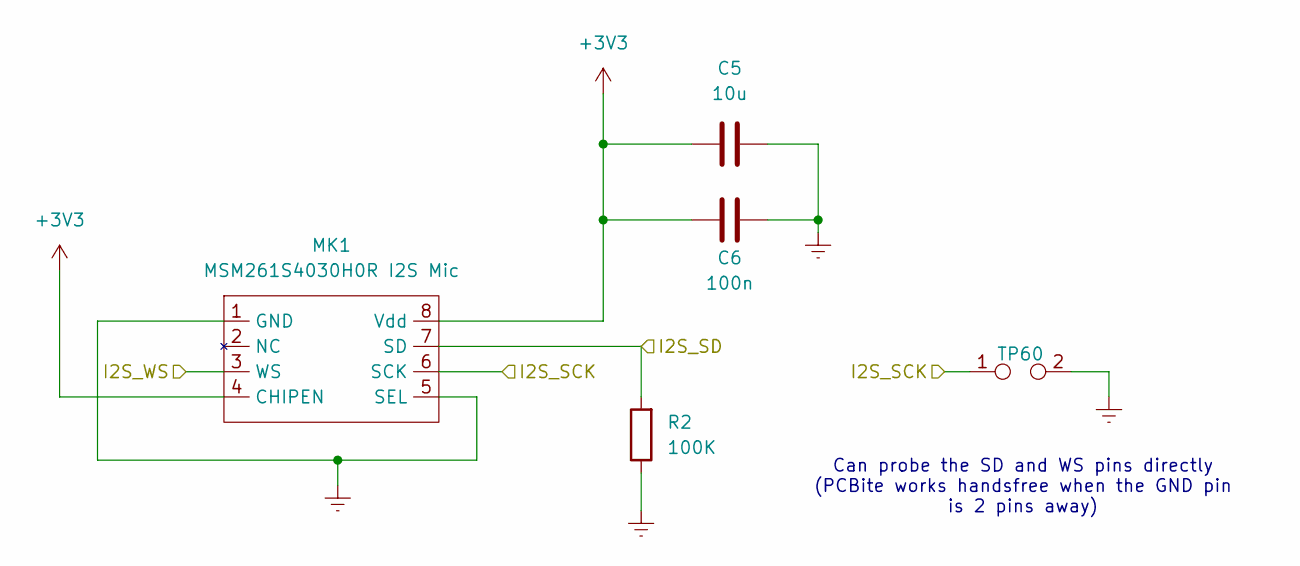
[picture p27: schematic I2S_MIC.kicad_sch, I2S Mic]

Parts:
C5: 10u; C_0603_1608Metric; MPN C1608X5R1A106K080AC
C6: 100n; C_0603_1608Metric; MPN C0603C104J3RACTU
MK1: MSM261S4030H0R I2S Mic; LGA-8_2x4_3.0x4.0mm_P1.0mm_Hand_Solder; MPN MSM261S4030H0R
R2: 100K; R_0603_1608Metric; MPN RP73PF1J100KBTDF
TP60: TestPoint_2Pole; D_MicroMELF

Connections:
+3V3: C5.2, C6.2, MK1.4 (CHIPEN), MK1.8 (Vdd); also elsewhere on the board
/I2S MIC/I2S_SCK: MK1.6 (SCK), TP60.1; also elsewhere on the board
/I2S MIC/I2S_SD: MK1.7 (SD), R2.2; also elsewhere on the board
/I2S MIC/I2S_WS: MK1.3 (WS); also elsewhere on the board
GND: C5.1, C6.1, MK1.1 (GND), MK1.5 (SEL), R2.1, TP60.2; also elsewhere on the board

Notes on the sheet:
Can probe the SD and WS pins directly (PCBite works handsfree when the GND pin is 2 pins away)

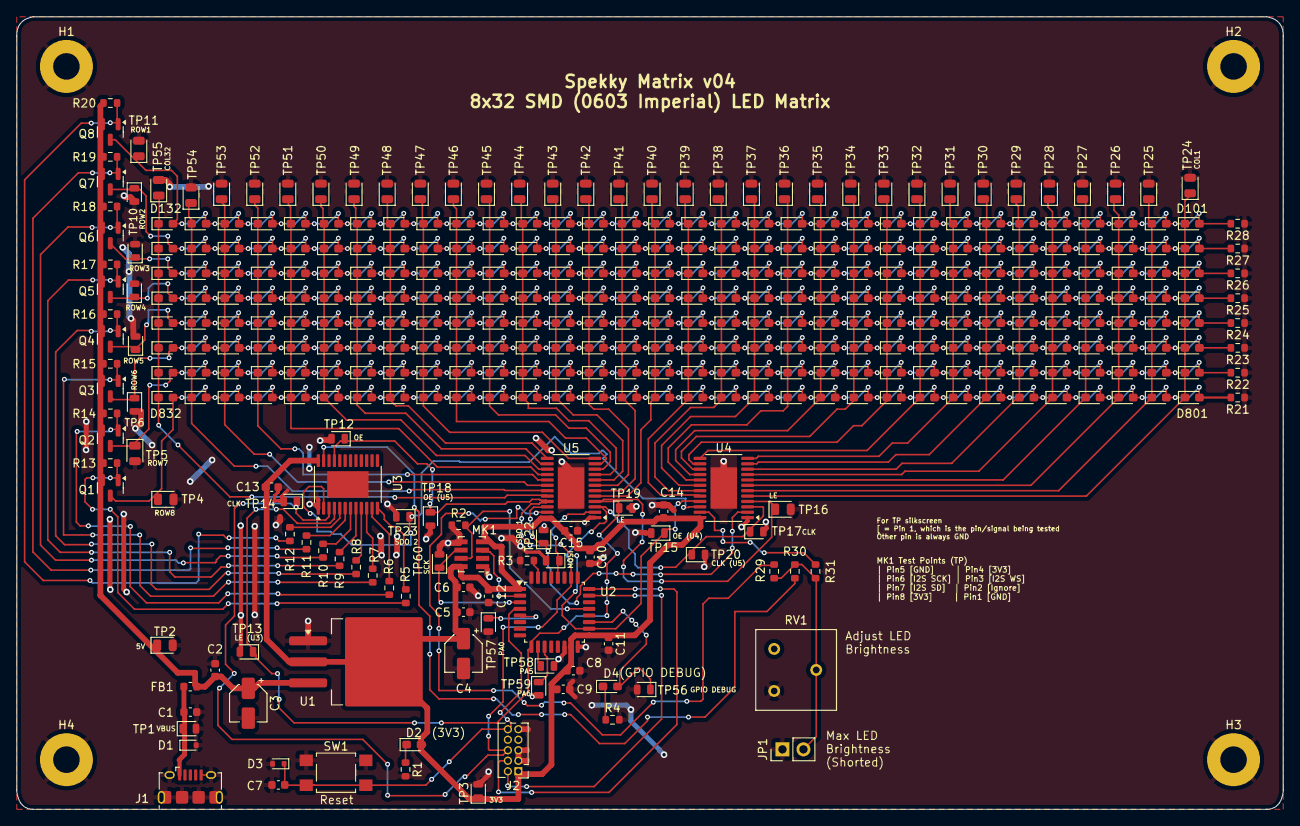
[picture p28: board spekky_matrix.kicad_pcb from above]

Board: 2 copper layers, 153.0 x 95.8 mm, 390 parts (0 on the bottom side), 83 nets.

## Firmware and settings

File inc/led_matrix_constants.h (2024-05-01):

#ifndef LED_MATRIX_CONSTANTS_H
#define LED_MATRIX_CONSTANTS_H

// Address mappings
#define ADDR_NOP       0x00U
// TOP = Led Matrix writing on PCB (row0)
// BOTTOM = array on PCB (row7)
// LEFT = DIN side
// RIGHT = DOUT side, writing a 1 in rowX will place a dot in the right most position
#define ADDR_ROW0      0x01U
#define ADDR_ROW1      0x02U
#define ADDR_ROW2      0x03U
#define ADDR_ROW3      0x04U
#define ADDR_ROW4      0x05U
#define ADDR_ROW5      0x06U
#define ADDR_ROW6      0x07U
#define ADDR_ROW7      0x08U
#define ADDR_DECODE    0x09U
#define ADDR_INTENSITY 0x0AU
#define ADDR_SCANLIMIT 0x0BU
#define ADDR_SHUTDOWN  0x0CU
#define ADDR_DISPTEST  0x0FU
// Alternative namses: 7-segment names
#define ADDR_DIGIT0    ADDR_ROW0
#define ADDR_DIGIT1    ADDR_ROW1
#define ADDR_DIGIT2    ADDR_ROW2
#define ADDR_DIGIT3    ADDR_ROW3
#define ADDR_DIGIT4    ADDR_ROW4
#define ADDR_DIGIT5    ADDR_ROW5
#define ADDR_DIGIT6    ADDR_ROW6
#define ADDR_DIGIT7    ADDR_ROW7
#define ADDR_BRIGHTNESS  ADDR_INTENSITY

// Data constants
#define DATA_SHUTDOWN_ON   0x00U
#define DATA_SHUTDOWN_OFF  0x01U
// Decode, set uses binary format e.g. 0b111 will set digit 7 for 7-segment display
// otherwise each bit refers to a different segment/line
#define DATA_DECODE_NONE           0x00U
#define DATA_DECODE_ALL_ROWS       0xFFU
#define DATA_DECODE_SET_ROWS(x)    (x)
#define DATA_INTENSITY_LEVEL1        0x01U // lowest brightness
#define DATA_INTENSITY_LEVEL2        0x02U
#define DATA_INTENSITY_LEVEL3        0x03U
#define DATA_INTENSITY_LEVEL4        0x04U
#define DATA_INTENSITY_LEVEL5        0x05U
#define DATA_INTENSITY_LEVEL6        0x06U
#define DATA_INTENSITY_LEVEL7        0x07U
#define DATA_INTENSITY_LEVEL8        0x08U
#define DATA_INTENSITY_LEVEL9        0x09U
#define DATA_INTENSITY_LEVEL10       0x0AU
#define DATA_INTENSITY_LEVEL11       0x0BU
#define DATA_INTENSITY_LEVEL12       0x0CU
#define DATA_INTENSITY_LEVEL13       0x0DU
#define DATA_INTENSITY_LEVEL14       0x0EU
#define DATA_INTENSITY_LEVEL15       0x0FU // highest brightness
#define DATA_SCANLIMIT_1_ROWS_MAX    0x00U // row 0
#define DATA_SCANLIMIT_2_ROWS_MAX    0x01U // row 0-1
#define DATA_SCANLIMIT_3_ROWS_MAX    0x02U // row 0-2
#define DATA_SCANLIMIT_4_ROWS_MAX    0x03U // row 0-3
#define DATA_SCANLIMIT_5_ROWS_MAX    0x04U // row 0-4
#define DATA_SCANLIMIT_6_ROWS_MAX    0x05U // row 0-5
#define DATA_SCANLIMIT_7_ROWS_MAX    0x06U // row 0-6
#define DATA_SCANLIMIT_8_ROWS_MAX    0x07U // row 0-7
#define DATA_DISPTEST_ON           0x01U
#define DATA_DISPTEST_OFF          0x00U
// Alternative names
#define DATA_DECODE_ALL_DIGITS     DATA_DECODE_ALL_ROWS
#define DATA_DECODE_SET_DIGITS(x)  DATA_DECODE_SET_ROWS(x)
#define DATA_SCANLIMIT_1_ROW_MAX   DATA_SCANLIMIT_1_ROWS_MAX
#define DATA_SCANLIMIT_TO_ROW0     DATA_SCANLIMIT_1_ROWS_MAX
#define DATA_SCANLIMIT_TO_ROW1     DATA_SCANLIMIT_2_ROWS_MAX
#define DATA_SCANLIMIT_TO_ROW2     DATA_SCANLIMIT_3_ROWS_MAX
#define DATA_SCANLIMIT_TO_ROW3     DATA_SCANLIMIT_4_ROWS_MAX
#define DATA_SCANLIMIT_TO_ROW4     DATA_SCANLIMIT_5_ROWS_MAX
#define DATA_SCANLIMIT_TO_ROW5     DATA_SCANLIMIT_6_ROWS_MAX
#define DATA_SCANLIMIT_TO_ROW6     DATA_SCANLIMIT_7_ROWS_MAX
#define DATA_SCANLIMIT_TO_ROW7     DATA_SCANLIMIT_8_ROWS_MAX
#define DATA_BRIGHTNESS_LEVEL1     DATA_INTENSITY_LEVEL1 // lowest brightness
#define DATA_BRIGHTNESS_LEVEL2     DATA_INTENSITY_LEVEL2
#define DATA_BRIGHTNESS_LEVEL3     DATA_INTENSITY_LEVEL3
#define DATA_BRIGHTNESS_LEVEL4     DATA_INTENSITY_LEVEL4
#define DATA_BRIGHTNESS_LEVEL5     DATA_INTENSITY_LEVEL5
#define DATA_BRIGHTNESS_LEVEL6     DATA_INTENSITY_LEVEL6
#define DATA_BRIGHTNESS_LEVEL7     DATA_INTENSITY_LEVEL7
#define DATA_BRIGHTNESS_LEVEL8     DATA_INTENSITY_LEVEL8
#define DATA_BRIGHTNESS_LEVEL9     DATA_INTENSITY_LEVEL9
#define DATA_BRIGHTNESS_LEVEL10    DATA_INTENSITY_LEVEL10
#define DATA_BRIGHTNESS_LEVEL11    DATA_INTENSITY_LEVEL11
#define DATA_BRIGHTNESS_LEVEL12    DATA_INTENSITY_LEVEL12
#define DATA_BRIGHTNESS_LEVEL13    DATA_INTENSITY_LEVEL13
#define DATA_BRIGHTNESS_LEVEL14    DATA_INTENSITY_LEVEL14
#define DATA_BRIGHTNESS_LEVEL15    DATA_INTENSITY_LEVEL15 // highest brightness

enum AddrRows {
	AddrRow0 = ADDR_ROW0
	, AddrRow1
	, AddrRow2
	, AddrRow3
	, AddrRow4
	, AddrRow5
	, AddrRow6
	, AddrRow7
};

#endif /* LED_MATRIX_CONSTANTS_H */

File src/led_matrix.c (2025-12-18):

#include <limits.h>

#include "led_matrix.h"
#include "spi.h"
#include "stm32g4xx_spi.h"

/*
 * LED Matrix (MAX7219)
 *
 * TOP    (writes appear right to left visually, see example below)
 * Row 0  0000 0001 (0x01)
 * Row 1
 * Row 2
 * Row 3
 * Row 4
 * Row 5
 * Row 6
 * Row 7  1111 1111 (0xFF)
 * BOTTOM
 *
 * LED Matrix (STP16CP05)
 * Row 1 --> 0x01 to U3 (Top)
 * ...
 * Row 8 --> 0x80 to U3 (Bottom)
 *
 *       Col 32     ...       Col 1
 *  0x8000 | 0x0000 ...  0x0000 | 0x0001
 *  U5     | U4     ...  U5     | U4
 *
 *  Cascade writes: array[3] = { U3, U4, U5 } (U3 == Rows, U4 == Cols16..01, U5 == Cols32..17)
 */

const uint8_t reverse_bits_lut[256] = {
	0x00, 0x80, 0x40, 0xC0, 0x20, 0xA0, 0x60, 0xE0, 0x10, 0x90, 0x50, 0xD0, 0x30, 0xB0, 0x70, 0xF0
	, 0x08, 0x88, 0x48, 0xC8, 0x28, 0xA8, 0x68, 0xE8, 0x18, 0x98, 0x58, 0xD8, 0x38, 0xB8, 0x78, 0xF8
	, 0x04, 0x84, 0x44, 0xC4, 0x24, 0xA4, 0x64, 0xE4, 0x14, 0x94, 0x54, 0xD4, 0x34, 0xB4, 0x74, 0xF4
	, 0x0C, 0x8C, 0x4C, 0xCC, 0x2C, 0xAC, 0x6C, 0xEC, 0x1C, 0x9C, 0x5C, 0xDC, 0x3C, 0xBC, 0x7C, 0xFC
	, 0x02, 0x82, 0x42, 0xC2, 0x22, 0xA2, 0x62, 0xE2, 0x12, 0x92, 0x52, 0xD2, 0x32, 0xB2, 0x72, 0xF2
	, 0x0A, 0x8A, 0x4A, 0xCA, 0x2A, 0xAA, 0x6A, 0xEA, 0x1A, 0x9A, 0x5A, 0xDA, 0x3A, 0xBA, 0x7A, 0xFA
	, 0x06, 0x86, 0x46, 0xC6, 0x26, 0xA6, 0x66, 0xE6, 0x16, 0x96, 0x56, 0xD6, 0x36, 0xB6, 0x76, 0xF6
	, 0x0E, 0x8E, 0x4E, 0xCE, 0x2E, 0xAE, 0x6E, 0xEE, 0x1E, 0x9E, 0x5E, 0xDE, 0x3E, 0xBE, 0x7E, 0xFE
	, 0x01, 0x81, 0x41, 0xC1, 0x21, 0xA1, 0x61, 0xE1, 0x11, 0x91, 0x51, 0xD1, 0x31, 0xB1, 0x71, 0xF1
	, 0x09, 0x89, 0x49, 0xC9, 0x29, 0xA9, 0x69, 0xE9, 0x19, 0x99, 0x59, 0xD9, 0x39, 0xB9, 0x79, 0xF9
	, 0x05, 0x85, 0x45, 0xC5, 0x25, 0xA5, 0x65, 0xE5, 0x15, 0x95, 0x55, 0xD5, 0x35, 0xB5, 0x75, 0xF5
	, 0x0D, 0x8D, 0x4D, 0xCD, 0x2D, 0xAD, 0x6D, 0xED, 0x1D, 0x9D, 0x5D, 0xDD, 0x3D, 0xBD, 0x7D, 0xFD
	, 0x03, 0x83, 0x43, 0xC3, 0x23, 0xA3, 0x63, 0xE3, 0x13, 0x93, 0x53, 0xD3, 0x33, 0xB3, 0x73, 0xF3
	, 0x0B, 0x8B, 0x4B, 0xCB, 0x2B, 0xAB, 0x6B, 0xEB, 0x1B, 0x9B, 0x5B, 0xDB, 0x3B, 0xBB, 0x7B, 0xFB
	, 0x07, 0x87, 0x47, 0xC7, 0x27, 0xA7, 0x67, 0xE7, 0x17, 0x97, 0x57, 0xD7, 0x37, 0xB7, 0x77, 0xF7
	, 0x0F, 0x8F, 0x4F, 0xCF, 0x2F, 0xAF, 0x6F, 0xEF, 0x1F, 0x9F, 0x5F, 0xDF, 0x3F, 0xBF, 0x7F, 0xFF
};


void set_spi_pin_details(struct LedSpiPin* spi_pin
                        , volatile uint32_t* assert_addr
                        , volatile uint32_t* deassert_addr
                        , unsigned int pin)
{
	*spi_pin = ((struct LedSpiPin) { assert_addr, deassert_addr, pin } );
}

void copy_spi_pin_details(struct LedSpiPin* dest, const struct LedSpiPin* src)
{
	*dest = *src;
}

void set_total_maxim_led_matrix_devices(struct MaximMax7219* matrix, int total_devices)
{
	matrix->total_devices = total_devices;
}

void set_total_stp16cp05_led_matrix_devices(struct Stp16cp05* matrix, int total_devices)
{
	matrix->total_devices = total_devices;
}

void set_led_matrix_device_cascade_bytes(uint16_t* matrix, unsigned int device_number
                                        , uint16_t tx_data)
{
	matrix[device_number] = tx_data;
}

uint16_t max7219_led_matrix_spi_data_out(uint8_t address, uint8_t data)
{
	unsigned int data_address = address & 0x0F; // address in only 4 bits wide
	return (data_address << 8) | data;
}


void led_matrix_transfer_data(struct LedSpiPin cs, volatile uint32_t* spi_tx_reg
                             , uint16_t tx_data, enum LedLatchData latch)
{
	// Pull CS low
	deassert_spi_pin(cs.deassert_address, cs.pin);

	// send data
	while (!spi_tx_ready_to_transmit()) {
		// wait for spi to become free
	}

	trigger_spi_transfer(spi_tx_reg, tx_data);

	while (!spi_tx_complete()) {
		// wait for spi to finish before pulling any spi pins
	}

	if (latch == LatchData) {
		// Pull CS high
		assert_spi_pin(cs.assert_address, cs.pin);
	}
}

void generic_led_matrix_transfer_data_cascade(struct LedSpiPin cs_or_le
                                             , volatile uint32_t* spi_tx_reg, uint16_t* tx_data
                                             , int total_devices
                                             , enum LedCascadeReverse reverse_order)
{
	if (reverse_order == ReverseCascade) {
		for (int i = total_devices - 1; i >= 0; --i) {
			led_matrix_transfer_data(cs_or_le, spi_tx_reg, tx_data[i], NoLatchData);
		}
	} else {
		for (int i = 0; i < total_devices; ++i) {
			led_matrix_transfer_data(cs_or_le, spi_tx_reg, tx_data[i], NoLatchData);
		}
	}

	// Latch data (pull CS high)
	assert_spi_pin(cs_or_le.assert_address, cs_or_le.pin);
}

void max7219_led_matrix_transfer_data_cascade(struct MaximMax7219 matrix
                                             , volatile uint32_t* spi_tx_reg, uint16_t tx_data
                                             , int device_number)
{
	// if X devices, must be a total of X calls to led_transfer(), one real, rest NOPs
	int initial_nops = matrix.total_devices - device_number - 1; // -1 for zero index
	uint16_t nop_data = max7219_led_matrix_spi_data_out(ADDR_NOP, 0x00);
	for (int pre = 0; pre < initial_nops; ++pre) {
		led_matrix_transfer_data(matrix.cs, spi_tx_reg, nop_data, NoLatchData);
	}

	led_matrix_transfer_data(matrix.cs, spi_tx_reg, tx_data, NoLatchData);

	for (int post = initial_nops + 1; post < matrix.total_devices; ++post) {
		led_matrix_transfer_data(matrix.cs, spi_tx_reg, nop_data, NoLatchData);
	}

	// Pull CS high
	assert_spi_pin(matrix.cs.assert_address, matrix.cs.pin);
}

void max7219_led_matrix_clear(struct MaximMax7219 matrix, volatile uint32_t* spi_tx_reg
                                , int device_number)
{
	uint16_t tx_data = 0;
	for (unsigned int i = ADDR_ROW0; i <= ADDR_ROW7; ++i) {
		tx_data = max7219_led_matrix_spi_data_out(i, 0x00);
		max7219_led_matrix_transfer_data_cascade(matrix, spi_tx_reg, tx_data, device_number);
	}
}

void max7219_led_matrix_init(struct MaximMax7219 matrix, volatile uint32_t* spi_tx_reg
                            , uint8_t brightness, int device_number)
{
	uint16_t tx_data = max7219_led_matrix_spi_data_out(ADDR_BRIGHTNESS, brightness);
	max7219_led_matrix_transfer_data_cascade(matrix, spi_tx_reg, tx_data, device_number);

	tx_data = max7219_led_matrix_spi_data_out(ADDR_DISPTEST, DATA_DISPTEST_OFF);
	max7219_led_matrix_transfer_data_cascade(matrix, spi_tx_reg, tx_data, device_number);

	tx_data = max7219_led_matrix_spi_data_out(ADDR_DECODE, DATA_DECODE_NONE);
	max7219_led_matrix_transfer_data_cascade(matrix, spi_tx_reg, tx_data, device_number);

	tx_data = max7219_led_matrix_spi_data_out(ADDR_SHUTDOWN, DATA_SHUTDOWN_OFF);
	max7219_led_matrix_transfer_data_cascade(matrix, spi_tx_reg, tx_data, device_number);

	tx_data = max7219_led_matrix_spi_data_out(ADDR_SCANLIMIT, DATA_SCANLIMIT_8_ROWS_MAX);
	max7219_led_matrix_transfer_data_cascade(matrix, spi_tx_reg, tx_data, device_number);

	max7219_led_matrix_clear(matrix, spi_tx_reg, device_number);
}
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

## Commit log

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2024-04-12 Replace LED blinking code with DAC setup code
    - Mininmal setup for DAC1CH1 module
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2024-04-23 Avoid duplicate function names for spi and dac Tx checks
    - Added spi_ prefix to Tx checking functions
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2024-04-23 Added initial support for driving led matrix
    - Unit tested too
    - Missing a spi check on whether data is ready to be sent or not
    [led_matrix.c, leds_suite.c]
2024-04-23 Add fff reset code for unit tests
    [leds_suite.c]
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2024-04-25 Corrected naming of scanlimit led constants
    [led_matrix.c, led_matrix_constants.h]
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2024-04-28 Swap address and data arguments around
    [led_matrix.c, leds_suite.c]
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2024-05-03 Added outputs of DIF fft of 125Hz sine input
    - Correct non-zero frequency bin outputs
    - However the magnitudes are incorrect, the 64th bin should have the
    highest magnitude with the other non-zero imaginary numbers being much
    much smaller which they aren't
    - Will try messing about with the SYLT config header to see if I can get
    more accurate results
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2024-05-06 Added dma hw setup for dac
    - STM32G4 series device uses DMAMUX to connect peripherals to DMA
    - G431 is category 2 device therefore DMAMUX channels 0-5 are mapped to
    DMA1 channels 1-6 and DMAMUX channels 6-11 are mapped to DMA2 channels
    1-6
    - There are no predefined DMA connections, we make them with DMAMUX,
    given a specific DMAMUX channel we must also configure the correct
    DMA1/2 channel appropriately (given the mapping above)
    - I've chosen DMAMUX channel 0 --> DMA1 channel 1 for simplicity
    - Note: This works with or without the request generator channel 0
    register having the request id of DAC1CH1 being set. I'm not a 100%
    sure the purpose of the request generator so will be leav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
2024-05-07 Now successfully building ARM CMSIS DSP
    - Missed out the linker option: "-Wl,-gc-sections" when using the
    -ffunction-sections and -fdata-sections gcc flags
    - Only using those gcc options for the ARM DSP objects as these options
    can break programs by potnetially removing any in use code
    - Will now test on hardware
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2024-05-07 Added output of ARM DSP
    - Everything is working as expected, correct bin index and magnitude
    peak (seen on gdb)
    - Dumped gdb array output to text with array indexes to make
    distinguishing real and imaginary values easier
    - Input has to be a complex float, such that x[n] = re(z) and x[n+1] =
    im(z)
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2024-05-08 Remove old c header file from python fft script
    - No longer needed, using ARM DSP, this header was for a different
    submodule
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2024-05-20 Place FreeRTOS hooks in its own file
    - Any type of RTOS error handling/hook will be placed in this file in
    the future
    - No header as the FreeRTOS and FreeRTOS tasks headers handle declaring
    the prototype function
    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
2024-05-21 Create oneshot fft timer task
    - I had issues with creating both a oneshot timer "task" and an actual
    preemptive task
    - Kept getting HardFault_Handler errors until I moved the array and
    struct as globals which than gave me a ApplicationStackOverflow error
    (tried this on the oneshot timer)
    - Was able to resolve the oneshot timer method by increasing the timer
    stack depth as the TmrSvc task was causing the stack overflow when
    looking at the ApplicationStackOverflow function
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2024-05-22 Replace dac task with FreeRTOS idle hook task
    - DAC task does nothing due to DMA handling the DAC
    - Replaced with the FreeRTOS idle hook task since it gets auto-assigned
    priority 0 (lowest)
    - Added the option for the idle task to yield (FreeRTOSConfig), if
    another priority 0 task is ready the idle hook will yield to not block
    any other priorty 0 tasks
2024-06-05 Added STM32 I2S setup for SPI2 module
    - Faced some issues here with my device, looking at the NucleoG431KB
    schematic, PF0 and PF1 (WS and CLK) are both unconnected. Solder
    bridges SB8 and SB11 need to be soldered in order to get an output on
    those pins. Verfied that both WS and CLK were working on my logic
    analyser
    - My I2S MEMS microphone also has a SEL pin which selects which channel
    the mic will output to, this will be tied to GND for the left channel
    so no pin assigment was made
    - Added AFH register macro as A11 falls into the alternate function
    register high output
    - Setup I2S to sample at a frequency of 44.1kHz, when using the HSI @
    16MHz
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2024-06-14 Add USART/UART initialisation
    - Would like to debug the I2S mic over UART
    - Already getting some readings from logic analyser but I'm not sure
    that the results look correct
2024-06-15 Added submodule for I2S debugging
    - This submodule will plot the output from an I2S mic from data gathered
    from PulseView
    - I personally set up a venv for the relavant packages needed
    - Jumped ahead and tested, submodule works as expected, will need to
    upload my Pulseview traces and waveforms in later commits
    - Do remember to provide the correct data width argument to this python
    script, example in readme uses 16, however I2S mics tend to use 18/24
    bit widths instead
2024-06-18 Add PulseView/Sigrok logic analyser traces
    - With the previous commit I can now graph the logic analyser I2S
    outputs
    - Now have logic analyser traces for:
    1) control (no sound)
    2) 1 kHz sine test tone (played on phone speakers in close proximity
    to Fermion I2S mic)
    3) A song played on my phone speakers (to see it's dynamic range, only
    a short burst, less than 5 secs)
    - Prefix traces with previous git commit SHA however the last relevant
    change to the I2S code was the changing to a 24/32 bit frame
    - Using the above prefix as I'll also be uploading the images too
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2024-06-18 Update python fft to verify PulseView/Sigrok data
    - Updating python fft script so we can get an idea of the FFT output
    from the PulseView data
    - There is a 1000 Hz frequency component on the FFT results (with some
    spectral leakage)
    - There is also a much higher DC component present on the FFT results
    - There is also some noise present on the mic as seen on the "control
    test" waveform, this noise can be seen on the FFT results too
    - Results are quite respectable even with lower FFT sizes e.g. 64-256,
    you just need to set a good offset into the data due to the initial
    00's present on the data out signal (I used 1250 when testing with
    these smaller FFT sizes)
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2024-06-19 Animate fft/ifft python graphs
    - Getting a rough estimate of how this would look on my led matrix
    - Currently grabbing FFT sized samples from the raw data without any
    overlap
    - This is achieved through a new generator function, which is used to
    define the start and end positions of the mic data list (which the
    fft and ifft will be performed on)
    - Will try to attempt at adding in some overlap which might improve
    stability
    - Note: This may look fine for now due to the input wave being a static
    frequency sine wave however if we instead took the music example the
    FFT results should jump around with this current implementation
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2024-06-23 Added DMA code for I2S mic
    - STM32 will write I2S mic data to DMA buffer
    - Initial DMA commit, I2S IRQ code still exists for now
    - Tested without I2S IRQ and it doesn't work so far, new test branch
    will be setup in an attempt to fix this issue (DMA buffer all zero's
    even though there is data on I2S data out line)
2024-06-23 Remove I2S RX IRQ code
    - Opting for DMA, IRQ is no longer needed
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2024-06-25 Fix STM32 I2S modules SD out pin
    - Although the I2S SD out becomes our input it must be configured
    as AF mode through GPIO MODE bits
    - Previous comment was misleading, will update all AF function comments
    in a future commit
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2024-06-26 Added new PulseView traces
    - PulseView traces for inverting the I2S idle CLK and a 100K pulldown
    resistor on the I2S SD line
    - Fermion I2S breakout mic also has a 100K pulldown res on SD line too
    as recommended on the I2S mics datasheet
    - Still a couple of non-zero values appear on the R channel but not as
    frequent as before
    - Also added the I2S data output which can be plotted with the
    SigPlotI2S submodule
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2024-06-26 Update ARM CMSIS DSP submodule
    - Issue with DSP submodule has already been resolved, no changes on my
    end
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2024-06-27 Generating saved animations from python fft
    - Save method doesn't work when the frames is generated through an
    iterator function
    - Added some commented out code to highlight how to save the animation
    - Saving animation:
    1) save each frame
    2) use ffmpeg to build video/gif from each frame
    3) delete 1)
    - Will be using these gif/mp4s in my readme hence they appear in this
    branch
2024-06-27 Move python fft plot title so it doesn't overlap axis
    - Moved secondary x-axis lower
    - Raised title from 0.98 to 0.995
    - Needed to avoid saved plot frames having overlapping text
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2024-09-07 Add freertos gdb python script
    - This is the freertos_gdb script file from FreeRTOS but with the
    tabulate module being removed and replaced with a function from
    espressif's freertos_gdb repo
    - This is so that the script works with python without any extra pip
    modules being needed
    - Commented out suspended tasks and waiting termination tasks as these
    caused GDB to print an error rather than the task list
    - Will look into how to resolve the latter issue in a future commit
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2024-09-11 Correctly support a variable number of led matrices
    - This version isn't hard coded like the previous ones
    - Made the led_matrix struct a global in order to pass in the total
    number of matrices for the FreeRTOS callback function
    - User can now setup a variable number of LED matrices without the need
    of editing the code (some editing the fft_constants header file will
    be needed however)
    [led_matrix_rtos.c]
2024-09-12 Update schematic
    - Fixed error in schematic one of the I2S signals was accidently
    connected to another one (SCK I believe)
    - Smaller A5 sheet
    - Using labels over crossing wires
    - Moved text into the sheet comments
    - Update readme file pointer for schematic
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2024-10-01 New fft led bar sensitivities
    - Skipping the associated unit test until we come up with the final
    values
    - Previous values are way too sensitive, all frequencies have about 4-5
    bars in ambient environments
    [led_matrix.c, leds_suite.c]
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2024-10-03 Python fft correctly scale dB FS fft graph
    - My 1kHz signal is now a much higher dB (dBFS) value ~ -3dB
    - Set limits of python graph
    - Now y-axis is dBFS, correct y-axis title
    - This should also work with the max amplitude square wave
2024-10-03 Python fft square wave correction
    - Cannot log a zero magnituded frequency component
    - Adjusted to small value so that it is graphed but occurs below the
    y-axis limits
    - You will need to zoom in onto the graph to see that the even number
    harmonics aren't graphed
2024-10-03 Add unit test for i2s conversion
    - This is the min/max limits for I2S to complex conversion function
    - Bits 31-8 are filled rather than 23-0 as I2S transmits MSB first so
    essentially the data becomes 24-bit LSB padded
    - Noticed no issues with regards to the FFT when using 24-bit LSB
    padding
    - Another note is the resistor is on SD pin is sometimes letting an
    extra bit or two appear on the output when it should be high
    impeadance. Again, I haven't noticed any issues so far
    - Due to the above two points I'll create a new branch to test out a
    24-bit output without any LSB padding for comparison
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2024-10-04 fft to db fs conversion with tests
    - FFT to dB FS conversion of a max amplitude square wave (24-bit LSB
    padding)
    - Did notice when printing out the dB FS array that the output is
    incredibly small, -118 dB FS for the 1st harmonic, my Python scrpit
    had the harmonic around -3.97dB. Indicating that 24-bit LSB padding is
    the incorrect format to provide the FFT function
    - The tests do verify the general behaviour of a square wave, very
    low/negative dB values for even harmonics and the odd harmonics should
    decrease in intensity for increasing harmonics of the fundamental
    - Makefile updated
    - Renamed RTOS FFT task to avoid it having the same name as the new
    source file
2024-10-04 Undo square wave test in rtos (working spekky matrix)
    - Spekky matrix wouldn't output to LEDs correctly the last 5 or so
    commits due to this test
2024-10-04 Correct array size in extern declaration
    [led_matrix_rtos.c]
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2024-10-05 Update leds after each fft
    - No longer using timer
    - Now LEDs update after each FFT task (which is around every ~4ms)
    [led_matrix_rtos.c]
2024-10-05 Iniitial crude attmept at fft averaging
    - Performing averaging inside FFT task initially then will migrate it
    to the LED task
    - Verified on hardware, looks like it's still updating too fast, test
    tones are less jittery (however adjacent peaks are a bit lower)
    - "Crude" attempt as there isn't anything stopping the DMA interrupt
    from triggering the FFT task which would partially overwrite the
    bin_mags buffer
2024-10-05 Increased fft averaging
    - Now using 6 FFTs to produce a single LED update, this seems to be the
    sweet spot, issue is the higher frequency content (+5kHz) seems to be
    harder to trigger (some type of weighting or equal loudness curve will
    need to be applied for post-processing)
2024-10-07 Correct fft double buffering for averaging
    - Incorrectly configured the if-else chain, needed to be a check for
    equality rather than a series of > checks
2024-10-07 Apply blackman harris window
    - Applied 4 term Blackman Harris window to the I2S data
    - Adjusted for processing loss too +3 dB
    - One issue I've noticed with Spekky Matrix is that the first three bins
    appear too high. That is no I2S mic connected to STM32 gives us DMA
    data which is DC e.g. max_value + 0j after the complex conversion.
    Which means there should only be a DC componenet which I'm not
    processing. However the first three bins are -3, -13 and -35dB FS
    while the rest sit at -150/-160. More investigation with Python needs
    to be done
    - Window function is the issue. Rectangular window works fine
2024-10-30 Correct maxim max 7219 component name in src code
    - MAX7219 not MAX2719
    [led_matrix.c, led_matrix_rtos.c, leds_suite.c]
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2025-01-25 Led matrix bar function partially supports 16x16 led matricies
    - Required for different LED matrix IC drivers, some expect 16-bit SPI
    transfers, others 8 bit
    - Currently only supporting 8 bits
    - Now supporting 16-bits for RightToLeft and LeftToRight led enum
    directions which supports 16-pixel width (currently hard coded for 8
    rows but could be expanded to 16 rows without any issues)
    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
    [led_matrix.c, led_matrix_rtos.c, leds_suite.c]
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2025-01-25 Correct unit test comment
    [leds_suite.c]
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2025-04-24 Add a generic function for cascaded led driver ics
    - New enum for reversal of cascaded data order e.g. if data is in an
    array as device1 then device 2, reversal will output device2 then
    device1 over SPI (otherwise it is output in the order it's stored in)
    - Added unit test
    [led_matrix.c, leds_suite.c]
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2025-05-22 Add stm32 nrst comment
    - Added a comment to inidicate the recommneded circuitry for the NRST
    pin as indicated in the STM32G4x datasheet
    - This circuitry is also in the Nucleo line of devices (with the
    additional ESD protection), so the circuit should function
    without any issues
    [STM32_MCU.kicad_sch, spekky_matrix.kicad_sch]
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2025-06-06 Add pcb constraint settings (oshpark)
    - Used OSHPark constraints and haven't had any issues with either
    Elecrow or OSHPark
    [spekky_matrix.kicad_pcb]
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2025-06-13 Rework 3v3 connections
    - All 3V3 nets are now connected
    [spekky_matrix.kicad_pcb]
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2025-06-25 Fix spi traces/vias
    - Issue with an unconnected via and a trace too close to a via
    - Both now fixed, no DRC issues appearing for SPI traces/vias now
    [spekky_matrix.kicad_pcb]
2025-06-25 Correct via sizes
    - Most via sizes were too large, resorted back to default via sizes
    except for vias using power signals (3V3/GND/5V etc.)
    [spekky_matrix.kicad_pcb]
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2025-06-26 Correct nrst switch connections
    - Moved ESD diode and capacitor to remove any stubbing on the
    transmission line
    [spekky_matrix.kicad_pcb]
2025-06-26 Fix led matrix row connections
    - Only had bad copper which didn't connect to led matrix row pins
    [spekky_matrix.kicad_pcb]
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2025-06-26 Fix unconnected row5 track
    [spekky_matrix.kicad_pcb]
2025-06-26 Fix unconnected rext1 track
    [spekky_matrix.kicad_pcb]
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2025-06-26 Added more clearance between row1 track and r19
    [spekky_matrix.kicad_pcb]
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2025-06-26 Increased clearance between vbus and 5v tracks
    [spekky_matrix.kicad_pcb]
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2025-06-26 Move c14's position on pcb
    - Gives more clearance for traces nearby
    [spekky_matrix.kicad_pcb]
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2025-06-26 Fix unconnected trace
    [spekky_matrix.kicad_pcb]
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2025-06-27 Add test points to schematic and pcb
    - Test points are in the form of a 0402 (Imperial) diode footprint with
    pin 1 denoting the signal being tested and pin 2 always being GND
    - Therefore the silkscreen GND has been omitted, follow the signal name
    to the "." which denotes pin 1
    - 0402 package is intended for a oscilloscope probe with the ground
    probe tip for a low impedance path to ground
    - ARM SWD test points can be via the hook clip along with a clip to
    ground nearby, as the SWD is a THT footprint I didn't feel the need to
    again expose out more pins for a SMD based test point
    - Since the pads for the I2S mic are already exposed, it seemed
    counterintuitive to then make additional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
    [LED_DRIVING.kicad_sch, POWER_SHEET.kicad_sch, spekky_matrix.kicad_pcb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]
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2025-06-27 Cleanup pcb view
    - Hidden a lot of fabrication text, especially resistor arrays or
    groups, only keeping the 1st and last text or just a single value (as
    they all share they same values in these cases)
    - Moved around a lot of the fabrication text to reduce the visual noise
    [spekky_matrix.kicad_pcb]
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2025-06-28 Add thermal reliefs for arm swd connector
    - No DRC errors for ARM SWD THT connector
    [spekky_matrix.kicad_pcb]
2025-06-28 Add thermal relief for u3 gnd pad
    - Again, no more DRC errors regarding U3 (LED matrix driver IC)
    [spekky_matrix.kicad_pcb]
2025-06-28 Fix thermal reliefs on test point pads for cols nets
    - No more DRC errors for those specific test points
    [spekky_matrix.kicad_pcb]
2025-06-28 Add thermal relief for tp14
    - No DRC errors or warnings now
    [spekky_matrix.kicad_pcb]
2025-06-29 Minor changes to tracks/vias for better signal integrity
    - Moving tracks/vias to create larger ground fill zones for better
    signal integrity
    - Also adding more clearance between certain tracks
    [spekky_matrix.kicad_pcb]
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2025-08-01 Correct 10k resistor part number
    [STM32_MCU.kicad_sch, spekky_matrix_bom.csv]
2025-08-01 Correct 100k resistor part number
    - Previous was a THT component, corrected to SMD 0603 imperial
    [I2S_MIC.kicad_sch, spekky_matrix_bom.csv]
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2025-09-23 Update pcb from schematic
    - Includes another MPN correction for a resistor
    [spekky_matrix.kicad_pcb]
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2025-11-01 Correct stm32 outputs for led driver ic
    - SPI CS is analogous to LE, but was instead mapped to OE which in my
    initial tests were tied to GND (all LEDs could be driven)
    - Now SPI CS has been renamed to OE and is still mapped to OE pin on the
    STP led driver IC
    - GPIO LE is now correctly mapped the LE input on the STP too
    [LED_DRIVING.kicad_sch, STM32_MCU.kicad_sch, spekky_matrix.kicad_sch]
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2025-11-03 Rename led spi struct related function
    - Function could be used for other led spi pins but function name didn't
    reflect that
    - Updated unit tests to use this new function name too
    [led_matrix.c, led_matrix_rtos.c, leds_suite.c]
2025-11-03 Stop maxim7219 initialisation function being called
    - No longer needed
    [led_matrix_rtos.c]
2025-11-03 Use spi port macros over gpio macros for struct init
    - Easier to maintain, just need to change the header file if any issues
    with ports or pin
    [led_matrix_rtos.c]
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2025-11-03 Use lower level struct as argument for spi cascade
    - Didn't need the LED matrix struct as an argument, can use a lower
    level struct instead
    [led_matrix.c, led_matrix_rtos.c, leds_suite.c]
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2025-12-06 Add 32-bit function for setting rows in led matrix
    - Using 32-bits to represent each column of data per row
    - Added new unit tests for some 32-bit checks
    - Some unit tests are broken now after changing how the shifting
    conversion works
    [led_matrix.c, leds_suite.c]
2025-12-06 Disable broken unit tests (for now)
    - Aiming to switch over to the new led matrix function eventually so
    will be ignoring these broken unit tests for now
    [leds_suite.c]
2025-12-06 Correctly test left shifting on unit tests
    - Need to make sure the data type is unsigned
    [leds_suite.c]
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2025-12-17 Add new led inversion function
    - Basic unit test for goto label (for skipping when no inversions take
    place)
    [led_matrix.c, leds_suite.c]
2025-12-17 Add support for vertical flips on led matrix
    - Added new unit test case
    [led_matrix.c, leds_suite.c]
2025-12-17 Add support for flipping the led matrix left/right
    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
    [led_matrix.c, leds_suite.c]
2025-12-17 Add unit test for flipping left/right and vertically
    [leds_suite.c]
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2025-12-17 Fix function call for updated matrix bars to row conversion
    - Missed adding this fix several commits ago
    [led_matrix_rtos.c]
2025-12-17 Fix asan errors
    - Left shift needs to be constrained otherwise a runtime error will
    occur
    - Reactivated previously disabled unit tests
    - All tests pass (with and without ASAN)
    [led_matrix.c, leds_suite.c]
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2025-12-18 Fix led ghosting
    - Only my previous bar pattern code didn't show any ghosting on the LEDs
    - Changing the pattern of the inversions caused ghosting
    - Fixed ghosting by blanking all LEDs on the row before switching to the
    next row
    - Adjacent row only has very minor ghosting for one LED (for this
    pattern)
    - Tested on hardware and works perfectly (all LEDs the same brightness)
    - Also flipped the LED matrix vertically and horizontally, essentially
    position 101 is the bottom left rather than the top right (for the
    PCB silkscreen)
    [led_matrix_rtos.c]
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2025-12-20 Reworked led ghosting function
    - Function worked by blanking the current row LEDs and then blanking the
    next rows LEDs too
    - Noticed I didn't remove the set row data for the STP tx_data prior to
    calling the ghosting function (which also performed the same action)
    - Current PCB can handle just blanking the next row to completly
    eliminate the LED ghosting
    [led_matrix_rtos.c]
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2026-01-04 Replace test point footprints
    - Quite difficult to probe the 0402 SMD sized test points with my PCBite
    probes
    - End up scraping up the PCB trying to probe my test points as the gap
    is too small (on the 0402 footprint)
    - The 0805 and microMELF footprints are appropriately sized for hands
    free probing
    - Used microMELF footprints where space was very tight (as the microMELF
    occupies a slightly smaller area)
    [LED_DRIVING.kicad_sch, POWER_SHEET.kicad_sch, STM32_MCU.kicad_sch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]
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
